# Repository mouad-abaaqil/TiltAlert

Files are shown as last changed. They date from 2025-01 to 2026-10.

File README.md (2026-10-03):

<p align="center">
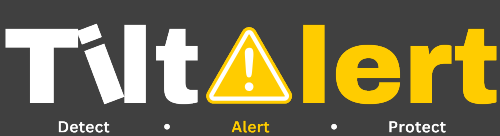
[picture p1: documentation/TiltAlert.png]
TiltAlert — Detect, Alert, Protect
  
</p>

<h1 align="center">Chaque choc laisse une trace.<br>Chaque colis mérite une preuve.</h1>

<p align="center">
  <strong>TiltAlert</strong> est la balise open source qui donne une mémoire aux colis fragiles.<br>
  Elle détecte chaque choc et chaque basculement, alerte sur place, et rend le trajet <em>lisible</em> : quand, à quelle force, avec quelle certitude de position.
</p>

<p align="center">
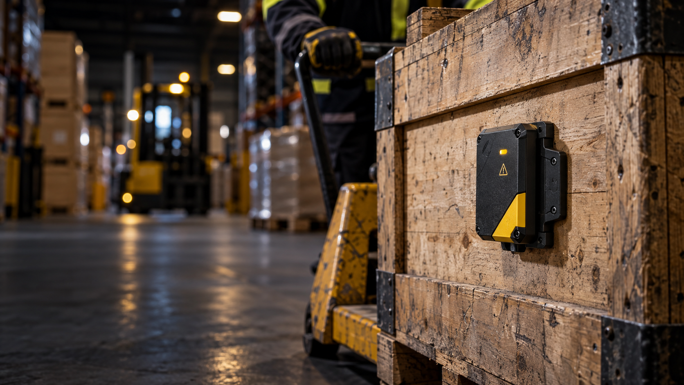
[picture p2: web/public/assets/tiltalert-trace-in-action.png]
Balise TiltAlert fixée à une caisse de transport en bois — visualisation du concept
  
</p>
<p align="center"><sub>Visualisation du concept (image générée, voir <a href="./documentation/IMAGE_PROMPT.md">le prompt</a>) — pas une photo d'un boîtier fabriqué.</sub></p>

---

## 1. Le problème : personne ne sait *quand* ça a cassé

Une optique de précision part de Paris et arrive à Lyon **fendue**. L'expéditeur, le transporteur et le destinataire voient le résultat. Personne ne peut dire **quand** le choc a eu lieu, **à quelle étape**, ni s'il s'agit d'une chute isolée ou d'un trajet entier mal manipulé.

Les étiquettes « FRAGILE » avertissent. Elles ne racontent rien. Résultat :

- des litiges où chacun renvoie la responsabilité à l'autre, **sans preuve** ;
- des assurances qui paient à l'aveugle, ou refusent à l'aveugle ;
- des étapes du transport qui restent mauvaises parce que **personne ne sait lesquelles** ;
- des indicateurs jetables qui disent « choc détecté » sans dire quand ni où.

## 2. La solution : une balise qui raconte le trajet

TiltAlert se fixe à une caisse. Elle fait trois choses, et les fait bien — **Detect, Alert, Protect** :

| | |
| --- | --- |
| **Detect — détecter** | Un accéléromètre dédié aux impacts (jusqu'à ±200 g) et un capteur d'inclinaison surveillent le colis en permanence, avec une consommation de veille de l'ordre du microampère. |
| **Alert — alerter** | LED, buzzer et bouton d'acquittement : après cinq basculements confirmés, l'alarme se déclenche **sur place**, là où quelqu'un peut encore réagir. |
| **Protect — prouver** | Chaque événement est enregistré dans un journal local (heure relative, valeur mesurée, état de la position). Le tableau de bord le transforme en **preuve intelligible** : carte, chronologie, rapport exportable. |

> **Pitch en 45 secondes.** « Vous expédiez une pièce fragile. Elle arrive cassée. Vous savez *quoi*, mais personne ne peut dire *quand* ni *à quelle étape*. TiltAlert donne une mémoire au colis : une balise réutilisable détecte l'incident, le journal le conserve et l'interface le rend compréhensible. Les équipes peuvent isoler les trajets problématiques au lieu de débattre sans preuve. Nous construisons un outil ouvert, réparable et adapté aux flux logistiques réels. »

### La règle d'or : on ne ment jamais sur la position

C'est le détail qui change tout. Un GNSS ne fonctionne pas dans un conteneur. Plutôt que de coller un point faux sur la carte, TiltAlert **affiche son niveau de certitude** :

| Statut | Ce que ça veut dire | Sur la carte |
| --- | --- | --- |
| ● **Position mesurée** | Un fix valide existe au moment exact de l'événement. | Marqueur plein |
| ○ **Dernière position connue** | Fix plus ancien : son âge est affiché, jamais présenté comme le lieu du choc. | Marqueur pointillé |
| — **Indisponible** | Aucun fix exploitable. | L'événement reste dans la chronologie, sans point |

Une preuve n'a de valeur que si elle dit aussi ce qu'elle ne sait pas.

---

## 3. Voir TiltAlert en action

### Le tableau de bord : « La vérité du trajet »

Carte interactive, journal d'incidents filtrable, replay du trajet, import de journal JSON, export CSV pour un litige ou un audit. [Code dans `web/`](./web/) — le trajet affiché est un **scénario de démonstration**, signalé comme tel dans l'interface.

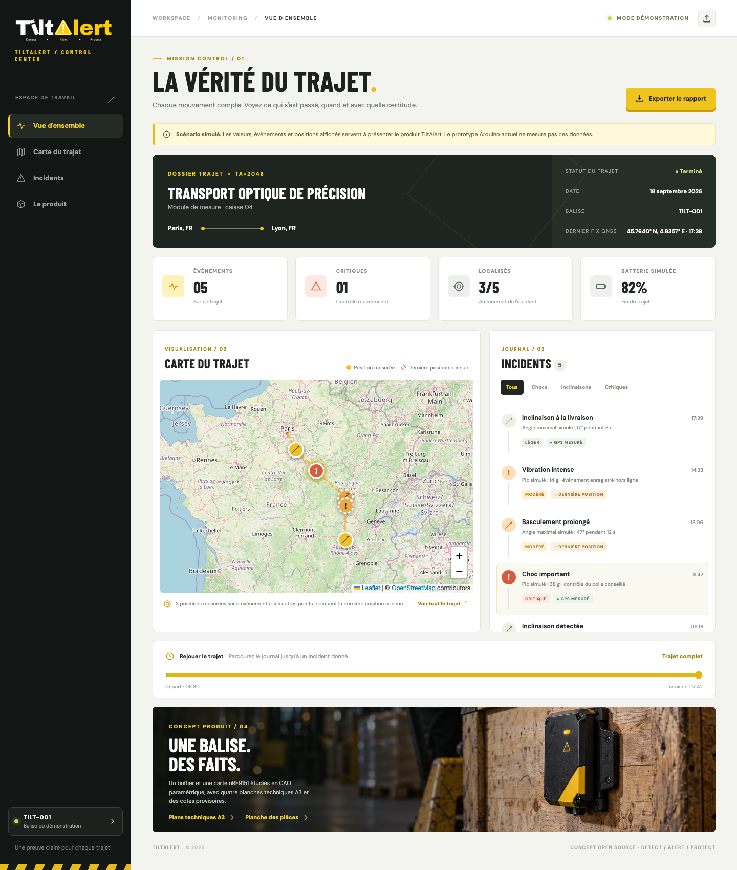
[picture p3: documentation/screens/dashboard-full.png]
Tableau de bord TiltAlert : dossier trajet, indicateurs, carte avec incidents mesurés et dernières positions connues, journal, replay


### Le blueprint : tous les composants sur une seule page

Vue éclatée de la balise V2 : **22 repères**, 25 lignes de nomenclature, axes de vissage, câble batterie. Tout est généré depuis un modèle 3D paramétrique, pas dessiné à la main.

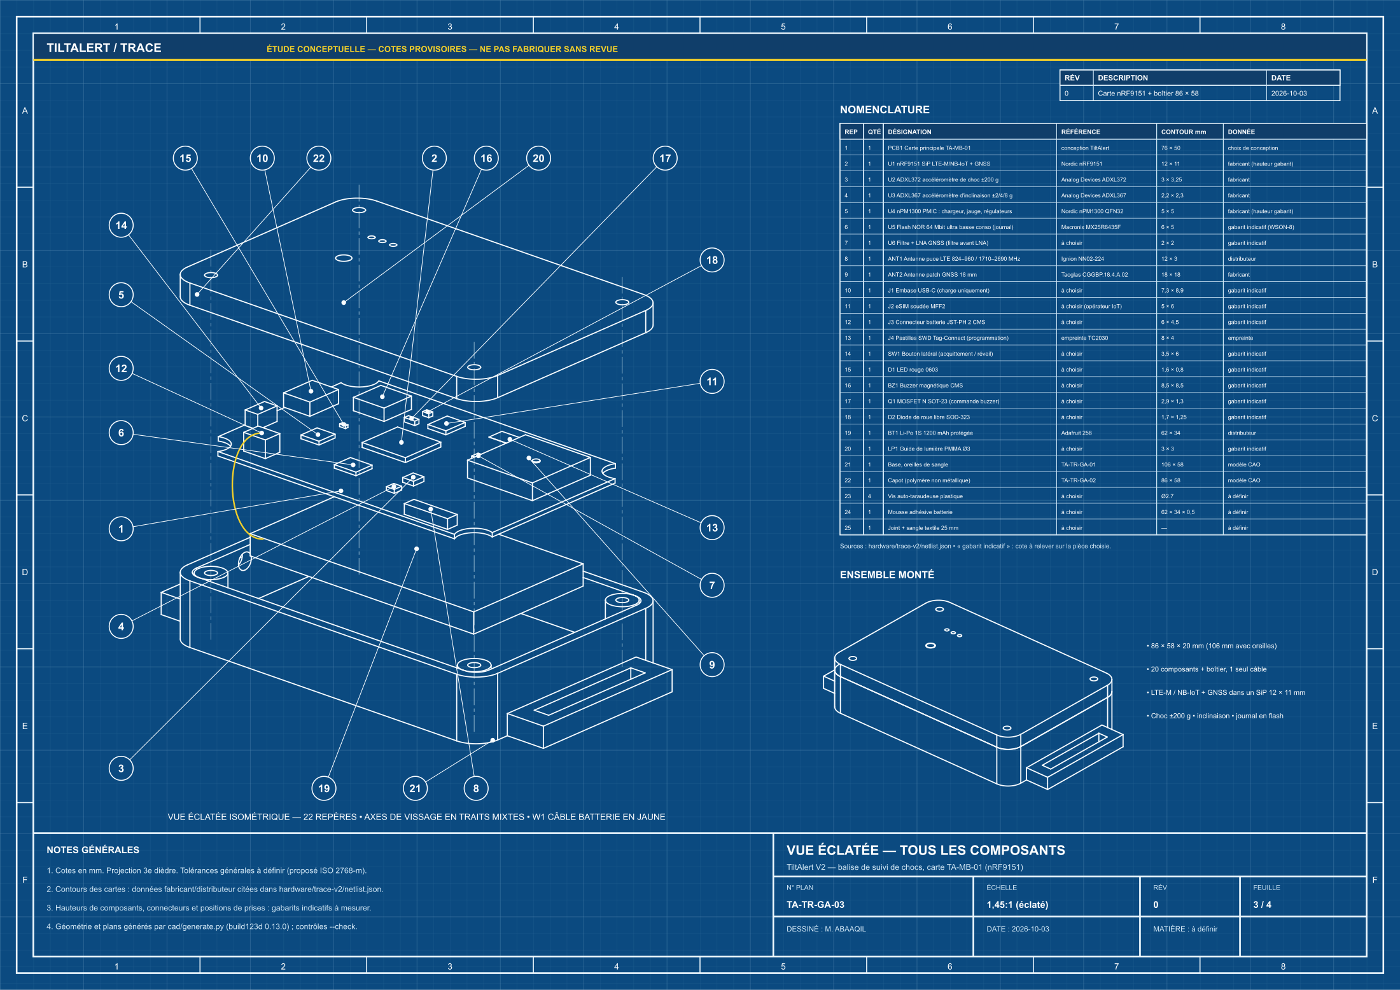
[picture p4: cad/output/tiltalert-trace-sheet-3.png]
Vue éclatée A3 de TiltAlert V2 : boîtier, carte nRF9151, capteurs, antennes, batterie, avec repères et nomenclature


<details>
<summary><strong>Voir les trois autres planches du jeu A3</strong> · <a href="./documentation/tiltalert-trace-plans-A3.pdf">PDF complet (4 pages)</a></summary>

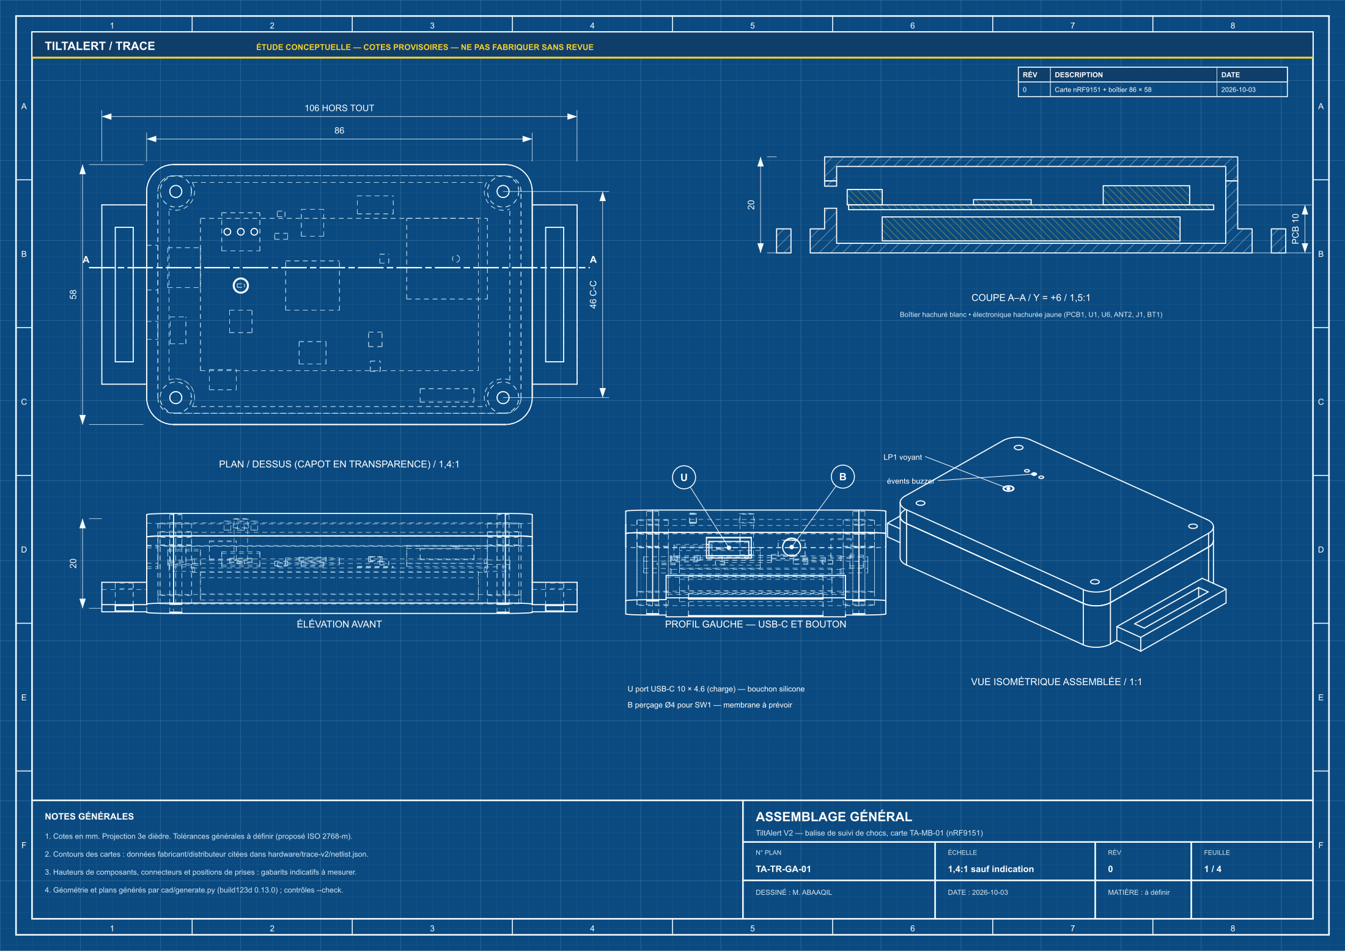
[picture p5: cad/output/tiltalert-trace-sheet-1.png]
Planche 1 : assemblage coté, coupe A–A, profil USB-C et bouton


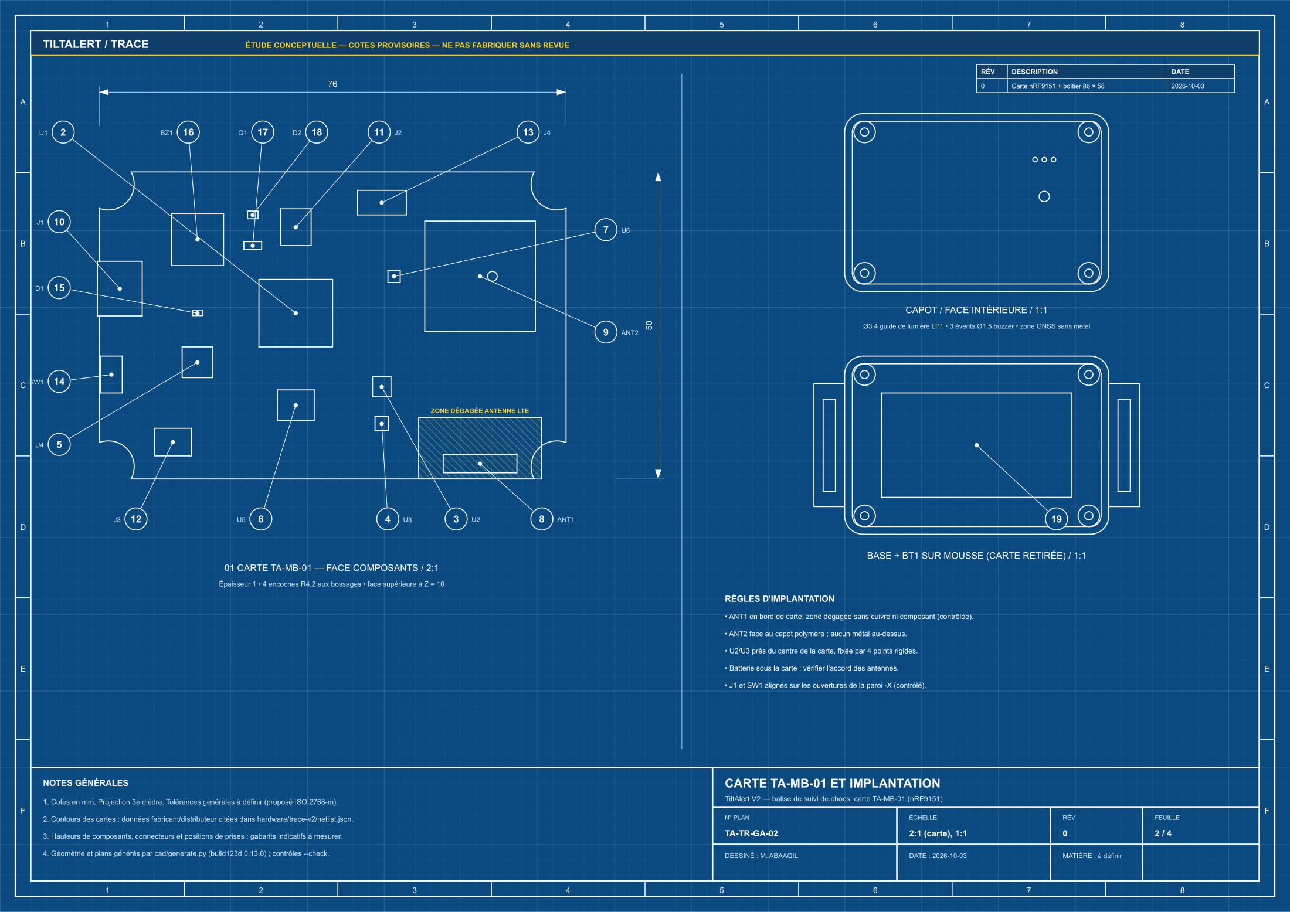
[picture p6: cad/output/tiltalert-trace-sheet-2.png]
Planche 2 : carte TA-MB-01 à 2:1, repères et zone dégagée de l'antenne LTE


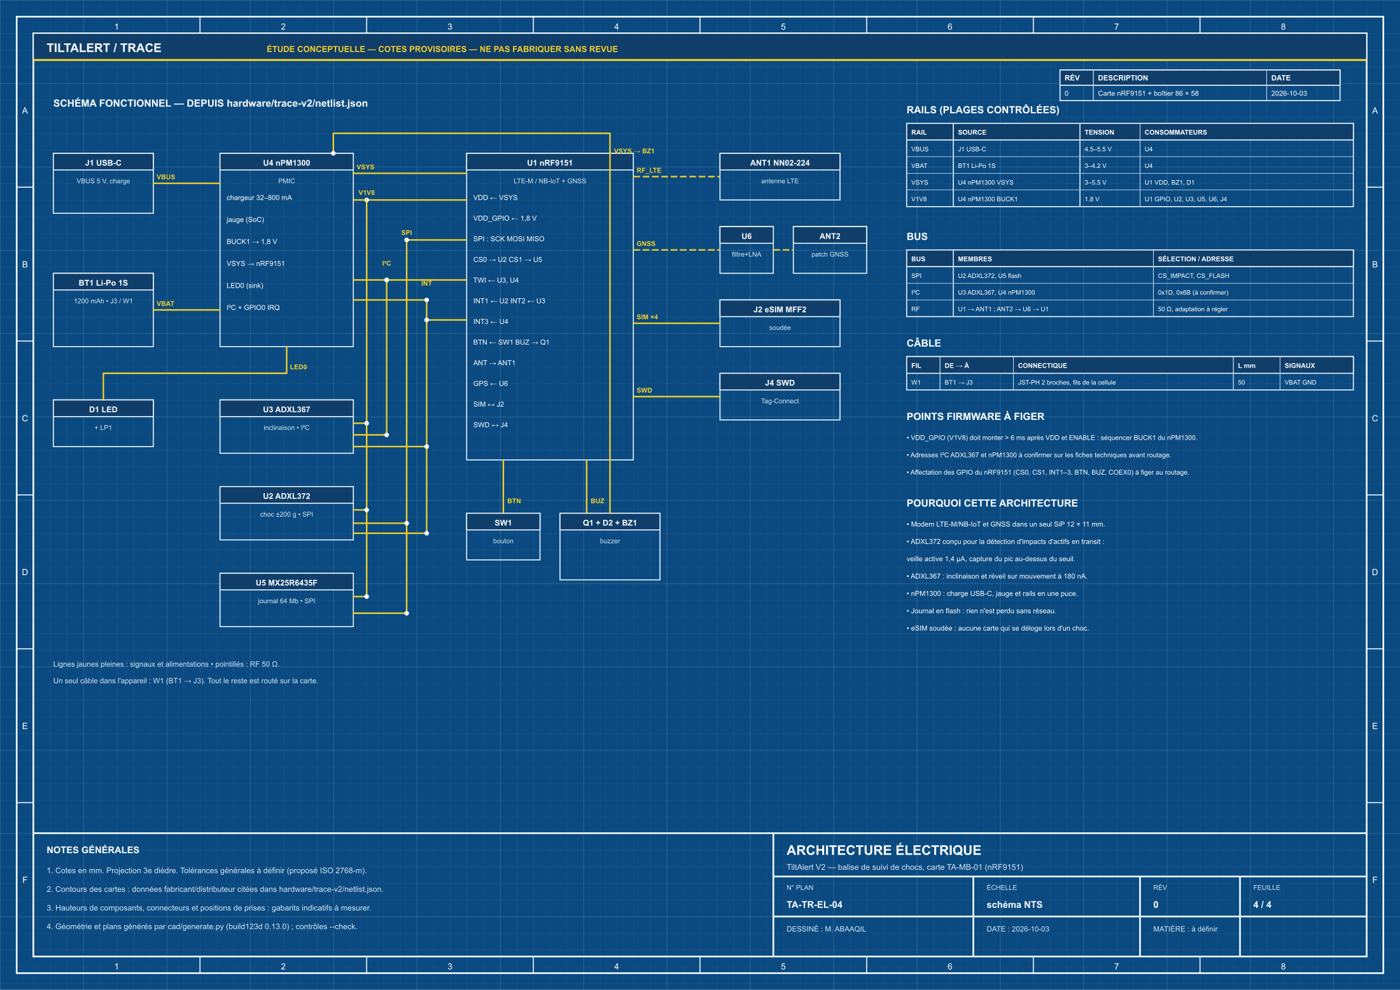
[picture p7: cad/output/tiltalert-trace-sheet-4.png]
Planche 4 : architecture électrique, rails, bus, câble


</details>

### Le blueprint de l'interface

Le tableau de bord lui-même est dessiné comme un plan : dix zones numérotées liées au vrai code, détail d'une carte d'incident, parcours utilisateur. [PDF](./documentation/tiltalert-interface-blueprint.pdf).

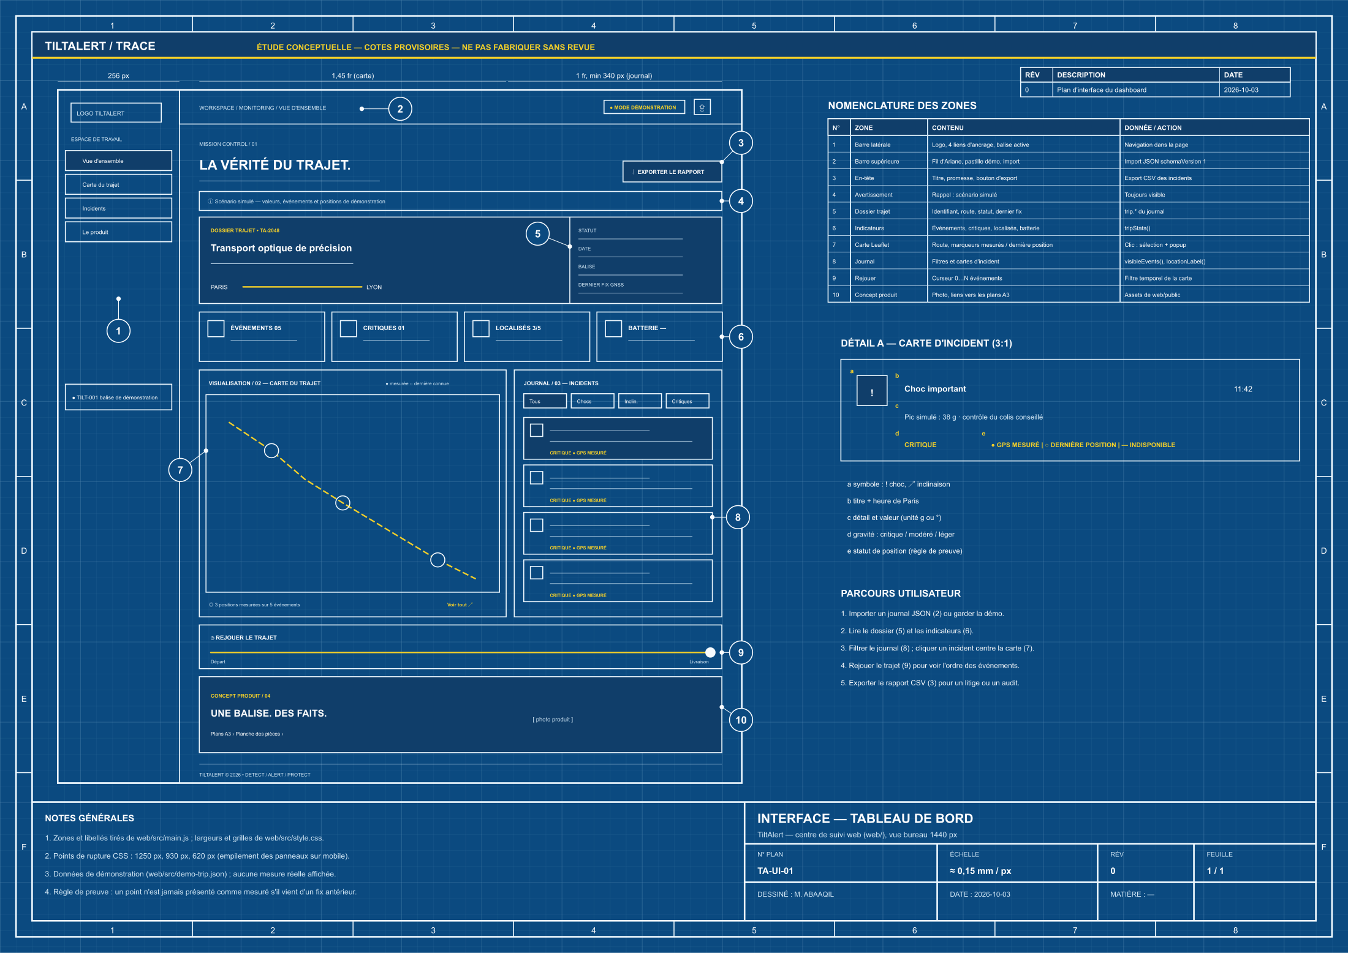
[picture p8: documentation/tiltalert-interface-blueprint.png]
Blueprint A3 de l'interface TiltAlert


### La preuve de concept : le vrai firmware, en simulation

Le firmware réel (`code/tiltalert.ino`) tourne dans un simulateur de l'Arduino Uno. Cinq basculements déclenchent l'alarme, un appui sur RESET l'acquitte.

| 1 · Cinq basculements → alarme | 2 · Acquittement |
| --- | --- |
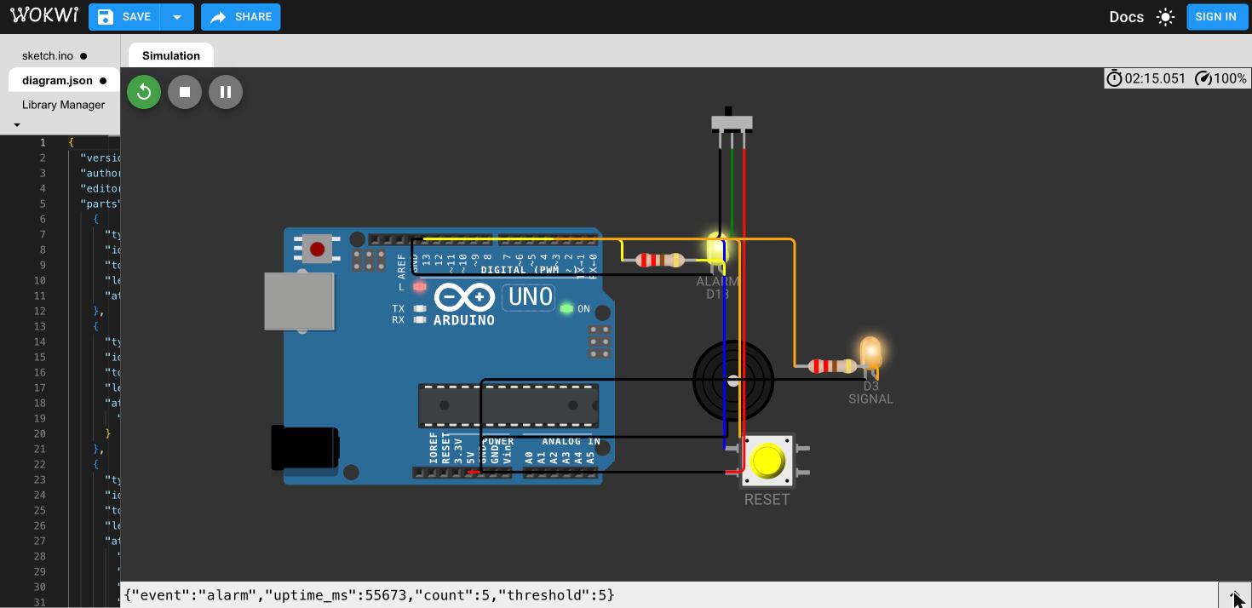
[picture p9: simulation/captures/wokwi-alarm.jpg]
Wokwi : alarme active, LED D13 et D3 allumées
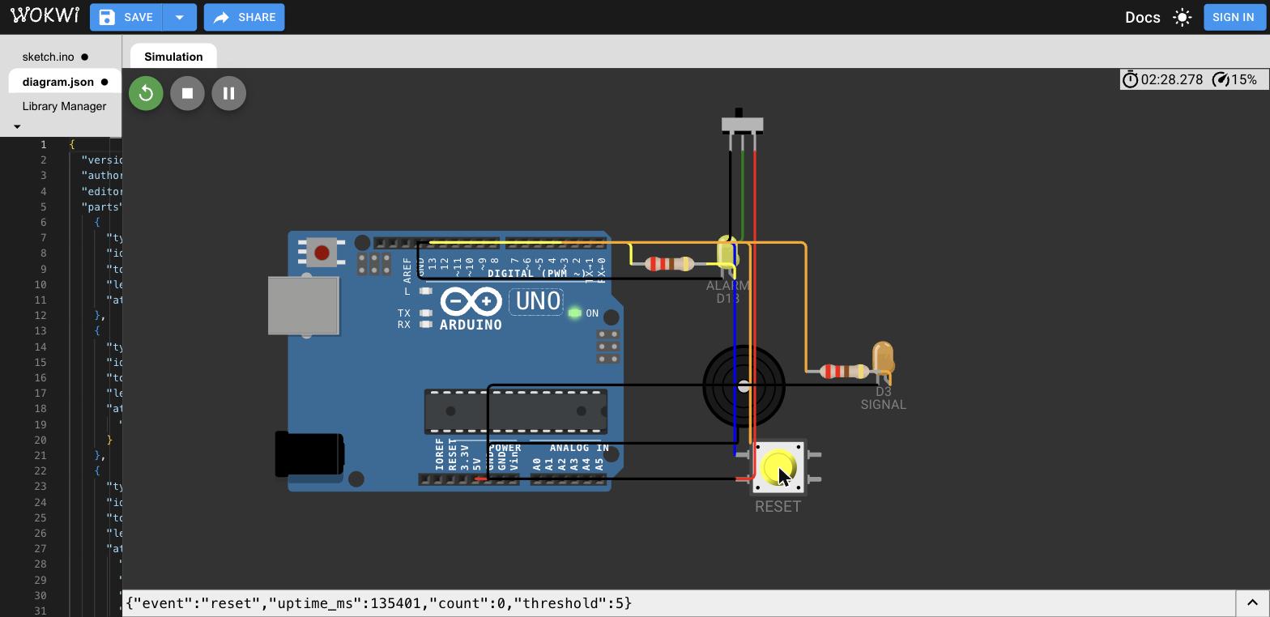
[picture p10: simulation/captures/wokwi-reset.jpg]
Wokwi : après RESET, LED éteintes
|  |  |

Le journal série prouve la séquence complète : `ready` → 5 × `tilt` → `alarm` → `reset`. [Capture du journal](./simulation/captures/wokwi-serial-log.jpg).

Le même prototype, documenté comme un vrai montage :

Schéma électrique A3 du prototype Uno

Implantation physique A3 sur breadboard, contrôlée contre la netlist

---

## 4. Sous le capot : la balise V2

Une **carte unique sur mesure** (TA-MB-01, 76 × 50 mm) dans un boîtier de **86 × 58 × 20 mm**. Chaque choix est sourcé dans [`hardware/trace-v2/`](./hardware/trace-v2/README.md).

| Fonction | Composant | Pourquoi celui-là |
| --- | --- | --- |
| Cerveau + réseau + GPS | [Nordic nRF9151](https://www.nordicsemi.com/Products/nRF9151) (12 × 11 mm) | Modem LTE-M/NB-IoT **et** GNSS intégrés : plus de modules empilés. |
| Chocs | [ADXL372](https://www.analog.com/en/products/adxl372.html), ±200 g | Conçu pour les impacts d'actifs en transit : veille active 1,4 µA, capture du pic au-dessus du seuil. |
| Inclinaison | [ADXL367](https://www.analog.com/en/products/adxl367.html) | Réveil sur mouvement à 180 nA. |
| Énergie | [nPM1300](https://www.nordicsemi.com/Products/nPM1300) | Charge USB-C, jauge de batterie et rails en une puce. |
| Mémoire | Flash 64 Mbit basse conso | Le journal survit sans réseau. |
| Antennes | Puce LTE + patch GNSS | Zone dégagée dédiée, contrôlée dans le modèle. |
| SIM | eSIM soudée | Aucune carte qui se déloge lors d'un choc. |

**Un seul câble** dans tout l'appareil (la batterie). Le reste est routé sur la carte.

### Un design qui se vérifie lui-même

À chaque génération des plans, un script contrôle que :

- les **20 composants tiennent** dans la cavité sans toucher une paroi, un bossage ou un autre composant (jeu ≥ 0,2 mm) ;
- chaque **tension d'alimentation** est dans la plage de chaque composant alimenté ;
- les **adresses I²C et sélections SPI** sont distinctes ;
- l'**antenne LTE** garde sa zone dégagée ;
- les ouvertures **USB-C et bouton** traversent bien la paroi en face de leurs composants.

Ces contrôles ont été éprouvés en leur injectant volontairement des erreurs (rail à 3,3 V, conflit d'adresse, composant dans la zone d'antenne) : ils les détectent.

```mermaid
flowchart LR
  A[ADXL372 : chocs ±200 g] --> M[nRF9151]
  B[ADXL367 : inclinaison] --> M
  G[GNSS intégré] --> M
  M --> J[(Journal flash)]
  J --> S[Export local ou LTE-M / NB-IoT]
  S --> W[Tableau de bord : carte + chronologie]
  M --> L[LED / buzzer / bouton]
  P[nPM1300 + Li-Po] --> M
```

---

## 5. Où en est-on, honnêtement

TiltAlert est un projet **ouvert et vérifiable**. Voici ce qui est prouvé, et ce qui reste à prouver avant toute promesse commerciale.

| ✅ Prouvé dans ce dépôt | 🔬 À prouver sur matériel réel |
| --- | --- |
| Firmware Uno : anti-rebond, seuil de 5 basculements, alarme latchée, acquittement, débordement de `millis()` — tests C++ et simulation du binaire compilé. | Calibration des seuils de choc et d'inclinaison sur un colis réel, taux de faux positifs. |
| Tableau de bord : format de trajet, statistiques, distinction des positions, export CSV — tests et build. | Journal qui survit à une coupure d'alimentation, sans doublons à la synchronisation. |
| Architecture V2 : netlist, rails, bus, encombrement et dégagements contrôlés par script. | Qualité des fixes GNSS en véhicule et en conteneur, accord des antennes. |
| Plans A3 générés depuis le modèle 3D, STEP/STL du boîtier et de l'assemblage. | Autonomie mesurée, tenue du boîtier, essais de transport. |

Les données du tableau de bord (événements, positions) sont **fictives**. Prix, autonomie, retour sur investissement : **non mesurés**. Les indicateurs d'impact et traceurs du marché existent déjà ([SpotSee](https://spotsee.io/wp-content/uploads/2019/07/Impact-Indicators-for-Packaging_English-01-19-2022-1.pdf), [Tive](https://www.tive.com/disposable-trackers/solo-pro-tracker)) : l'ambition de TiltAlert est une approche **ouverte, réparable et lisible**, avec une preuve qui dit ce qu'elle ne sait pas.

**Marché visé :** transport de pièces industrielles, matériel audiovisuel, objets fragiles de valeur. **Modèle à tester :** vente ou location de balises, puis abonnement pour la synchronisation et les rapports d'équipe.

### La suite

1. Écrire le firmware V2 sur une carte de développement [Nordic Thingy:91 X](https://docs.nordicsemi.com/r/bundle/ug_thingy91x/page/ug/thingy91x/intro/frontpage.html) : détection d'impacts, journal, envoi LTE-M, fix GNSS.
2. Router le PCB à 4 couches, revue RF.
3. Monter, mesurer, calibrer sur des chocs étalonnés.
4. Exporter de vrais journaux au format du tableau de bord.
5. Prototyper le boîtier et passer des essais de transport.

---

## 6. Explorer le dépôt

| Livrable | Contenu |
| --- | --- |
| [Tableau de bord](./web/) | Carte, chronologie, filtres, replay, import JSON, export CSV. |
| [Plans techniques A3](./documentation/tiltalert-trace-plans-A3.pdf) | 4 planches : assemblage, carte, vue éclatée + nomenclature, architecture électrique. |
| [Blueprint de l'interface](./documentation/tiltalert-interface-blueprint.pdf) | Zones numérotées, nomenclature, parcours utilisateur. |
| [Carte V2 nRF9151](./hardware/trace-v2/README.md) | Choix des composants, contrôles, points à lever avant routage. |
| [Modèle CAO](./cad/README.md) | build123d paramétrique ; exports STEP/STL (base, capot, assemblage complet). |
| [Architecture V2](./documentation/TRACE_ARCHITECTURE.md) | Flux d'un incident, règle de localisation, contrat de données. |
| [Prototype Uno](./hardware/validated-uno/README.md) | Netlist, schéma corrigé, implantation breadboard, nomenclature. |
| [Firmware](./code/tiltalert.ino) · [cœur testable](./code/TiltAlertCore.h) | Machine à états sans dépendance Arduino, sortie série JSON Lines. |
| [Simulation](./simulation/README.md) | AVR (binaire réel), circuit Wokwi, [captures](./simulation/captures/), [guide Tinkercad](./simulation/tinkercad/README.md). |
| [Cahier des charges original](./documentation/REPORT.md) | Archive de la première version. |

## 7. Reproduire

```bash
# Tests du firmware (C++) et du tableau de bord
sh tests/run.sh
cd web && npm ci && npm test && npm run build && cd ..

# Plans mécaniques et architecture V2 (Python 3.12, rsvg-convert)
python3.12 -m venv .venv
.venv/bin/python -m pip install -r cad/requirements.txt
.venv/bin/python cad/generate.py --check      # contrôles seuls
.venv/bin/python cad/generate.py              # plans, STEP, STL

# Planches du prototype Uno et blueprint de l'interface
python3 hardware/validated-uno/generate.py
python3 documentation/interface/generate.py

# Simulation du vrai firmware (arduino-cli + avr-gcc requis, voir simulation/README.md)
cd simulation && npm ci && npm test
```

**Lancer le tableau de bord :** `cd web && npm ci && npm run dev`, puis ouvrir l'adresse indiquée par Vite. Prérequis : Node.js 20.19+ ou 22.12+. La carte utilise [Leaflet](https://leafletjs.com/) et [OpenStreetMap](https://www.openstreetmap.org/copyright) (connexion Internet pour le fond de carte, aucune clé API).

**Monter le prototype Uno :** [schéma](./hardware/validated-uno/tiltalert-uno-electrical.pdf) et [implantation](./hardware/validated-uno/tiltalert-uno-physical.svg). Broches : D2 contact d'inclinaison (avec rappel 10 kΩ vers GND si le contact est nu), D3 buzzer **actif**, D13 LED + 220 Ω, D12 bouton vers GND (`INPUT_PULLUP`). Le fichier historique `hardware/wiring_diagram.brd` relie par erreur +5 V et GND : **ne pas le suivre**.

---

<p align="center">
  <strong>TiltAlert</strong> · Detect · Alert · Protect<br>
  <sub>Projet sous <a href="./LICENSE">licence MIT</a>. Cotes et architecture de conception, non validées pour la fabrication.</sub>
</p>

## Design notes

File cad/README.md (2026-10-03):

# TiltAlert — étude mécanique paramétrique

Ce dossier contient le **concept de boîtier et d'implantation de la V2** (carte TA-MB-01, nRF9151), distinct du montage Arduino Uno actuel. Les dimensions sont **provisoires**. Le PCB n'est pas routé ; l'étanchéité, la visserie et les tolérances d'assemblage ne sont pas validées. `components.py` modélise les composants et `drafting.py` le cadre A3 commun.

## Reproduire les exports

Sur macOS avec Python 3.12 et `rsvg-convert` :

```sh
python3.12 -m venv .venv
.venv/bin/python -m pip install -r cad/requirements.txt
.venv/bin/python cad/generate.py --check
.venv/bin/python cad/generate.py
```

Le modèle, la carte peuplée TA-MB-01 (contours sourcés dans `hardware/trace-v2/netlist.json`) et les quatre plans A3 sont générés depuis les paramètres `Dimensions` de [`generate.py`](generate.py). Les cotes, les positions des bossages, la coupe A–A, les vues orthographiques et la vue éclatée sont calculées depuis la même géométrie. `rsvg-convert` transforme les SVG en PDF et PNG. Tous les fichiers produits sont dans [`output/`](output/).

| Fichier | Usage |
|---|---|
| `tiltalert-trace-sheet-1.svg/.pdf/.png` | Assemblage : dessus, face, profil USB-C/bouton, coupe A–A, isométrie. |
| `tiltalert-trace-sheet-2.svg/.pdf/.png` | Carte TA-MB-01 à 2:1 avec repères et zone dégagée LTE, capot intérieur, batterie. |
| `tiltalert-trace-sheet-3.svg/.pdf/.png` | Vue éclatée repérée et nomenclature complète. |
| `tiltalert-trace-sheet-4.svg/.pdf/.png` | Architecture électrique : schéma fonctionnel, rails, bus, câble. |
| `tiltalert-trace-assembly.step` | Assemblage complet : boîtier, carte, composants, batterie. |
| `tiltalert-trace-base.step/.stl` | Solide de la base conceptuelle. |
| `tiltalert-trace-lid.step/.stl` | Solide du capot conceptuel. |

Le code de génération vérifie les dimensions extérieures, les volumes positifs, le perçage des quatre bossages, les ouvertures USB-C et bouton, la netlist V2 (rails, bus, câble) et l'absence de contact entre composants, parois et bossages (jeu ≥ 0,2 mm), y compris la zone dégagée de l'antenne LTE. Le script copie ensuite les feuilles vers `documentation/` et `web/public/assets/`. Ce contrôle géométrique ne remplace pas un essai d'impression, une revue mécanique, ni une validation de fabrication.

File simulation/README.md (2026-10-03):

# Simulation du firmware Uno

`npm test` compile **le vrai `code/tiltalert.ino`** avec le cœur Arduino AVR puis exécute le fichier Intel HEX dans [avr8js](https://github.com/wokwi/avr8js). Le script pilote les broches du microcontrôleur virtuel, écoute l'UART et vérifie D13 (LED) et D3 (buzzer). Le résultat reproductible est `evidence/avr8js-run.json`.

Pré-requis : Node 20.19+, `arduino-cli`, cœur `arduino:avr`, et un compilateur AVR utilisable par votre machine. Sur macOS ARM sans Rosetta, le compilateur AVR officiel Arduino est x86_64 : installer le compilateur natif avec `brew tap osx-cross/avr && brew trust osx-cross/avr && brew install avr-gcc`, puis `brew install universal-ctags`. Le script détecte ces outils dans le `PATH`; `AVR_COMPILER_PATH=/opt/homebrew/bin/ npm test` permet de fixer explicitement le compilateur.

```sh
arduino-cli core update-index
arduino-cli core install arduino:avr
cd simulation
npm ci
npm test
```

Le script de compilation copie le corps du sketch tel quel dans une unité C++ avec `#include <Arduino.h>` ; cela contourne la génération automatique de prototypes d'Arduino CLI, incompatible ici avec la variante de ctags ARM. Le scénario vérifie le démarrage, rejette un rebond de 10 ms, produit cinq transitions LOW→HIGH confirmées sur D2, confirme l'alarme sur D13 et D3, puis appuie sur le bouton D12 pour la réinitialiser. La simulation vérifie la logique et la correspondance des broches du firmware ; elle ne mesure ni les courants, ni l'acoustique du KY-012, ni le comportement physique du KY-020.

`wokwi/diagram.json` offre une version visuelle du même câblage. Le switch D2 sélectionne 0 V ou 5 V pour reproduire l'état logique OUT du KY-020 ; maintenir chaque position plus de 40 ms. Le bouton D12 correspond au reset. La LED orange supplémentaire témoigne de la sortie D3, car le buzzer piézo passif proposé par Wokwi ne représente pas exactement le module **actif** KY-012 alimenté en continu. `wokwi/sketch.ino` est généré depuis le firmware avec `npm run wokwi:generate` ; il ne doit pas être modifié à la main. Le même fichier sert au montage [Tinkercad](./tinkercad/README.md).

Le 3 octobre 2026, un essai interactif dans Wokwi (`diagram.json` + `sketch.ino` chargés tels quels) a affiché successivement `ready`, cinq événements `tilt` puis `alarm` à `count=5`, avec les LED D13 et D3 allumées, puis `reset` à `count=0` après appui sur RESET, LED éteintes. Les [captures](./captures/) le montrent : [démarrage](./captures/wokwi-ready.jpg), [alarme](./captures/wokwi-alarm.jpg), [acquittement](./captures/wokwi-reset.jpg) et [journal série complet](./captures/wokwi-serial-log.jpg). Le reset est aussi couvert par le test AVR automatique. Remarque de reproduction : l'onglet doit être visible, sinon le navigateur ralentit la simulation à quelques pour cent et les basculements sont trop brefs pour passer l'anti-rebond de 40 ms. Le [chronogramme SVG](./evidence/avr8js-timeline.svg) est généré depuis la trace réelle par `python3 generate-evidence.py` ; il montre les cinq événements, l'alarme et le reset, sans inventer de mesure analogique.

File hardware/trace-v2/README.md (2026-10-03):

# TiltAlert V2 — carte TA-MB-01 (nRF9151)

**Statut : architecture de conception sourcée.** Le PCB n'est ni routé, ni fabriqué, ni testé. Ce dossier ne décrit pas le prototype Uno de `code/` : celui-ci reste la preuve de concept logique.

La V2 remplace la pile de modules MKR envisagée au départ par **une seule carte sur mesure**. Le modem cellulaire et le GNSS sont intégrés dans un même boîtier SiP, et des capteurs conçus pour le suivi de colis sur batterie complètent la carte. Le boîtier passe ainsi d'environ 124 × 84 × 36 mm (encombrement de la pile MKR) à **86 × 58 × 20 mm**.

## Plans

| Planche | Contenu |
|---|---|
| [Feuille 1 — assemblage](../../cad/output/tiltalert-trace-sheet-1.pdf) | Vues cotées, coupe A–A à travers U1/ANT2/J1, profil USB-C + bouton, isométrie. |
| [Feuille 2 — carte et implantation](../../cad/output/tiltalert-trace-sheet-2.pdf) | Face composants 2:1 avec repères, zone dégagée de l'antenne LTE, capot intérieur, batterie. |
| [Feuille 3 — éclaté et nomenclature](../../cad/output/tiltalert-trace-sheet-3.pdf) | Vue éclatée repérée, 25 lignes de nomenclature avec statut de chaque cote. |
| [Feuille 4 — architecture électrique](../../cad/output/tiltalert-trace-sheet-4.pdf) | Schéma fonctionnel, rails contrôlés, bus, câble unique, points firmware. |

Le jeu complet est aussi disponible dans [`tiltalert-trace-plans-A3.pdf`](../../documentation/tiltalert-trace-plans-A3.pdf). Les quatre feuilles sont générées par `cad/generate.py` à partir de [`netlist.json`](./netlist.json) et du modèle 3D.

## Choix des composants

| Rep. | Composant | Pourquoi |
|---|---|---|
| U1 | [Nordic nRF9151](https://www.nordicsemi.com/Products/nRF9151) SiP 12 × 11 mm | Modem LTE-M/NB-IoT **et** GNSS intégrés, processeur Cortex-M33 applicatif. Remplace le MKR NB 1500 et le module GNSS séparé. |
| U2 | [ADXL372](https://www.analog.com/en/products/adxl372.html) ±200 g | Conçu pour la surveillance d'impacts sur des biens en transit : veille active de 1,4 µA, capture du seul pic au-dessus du seuil, FIFO profond. |
| U3 | [ADXL367](https://www.analog.com/en/products/adxl367.html) ±2/4/8 g | Inclinaison par la gravité et réveil sur mouvement à 180 nA. |
| U4 | [nPM1300](https://www.nordicsemi.com/Products/nPM1300) | Chargeur 32–800 mA, jauge, deux régulateurs abaisseurs et pilotes de LED dans une seule puce. |
| U5 | Macronix MX25R6435F, 64 Mbit | Journal non volatil : rien n'est perdu sans réseau. Courant de 7 nA en mise en veille profonde. |
| U6 + ANT2 | Filtre puis LNA + patch [Taoglas CGGBP.18.4.A.02](https://www.taoglas.com/product/cggbp-18-4-a-02-gpsglonassbeidou-patch-antenna-18mm-2) | Topologie [recommandée par Nordic](https://docs.nordicsemi.com/r/bundle/nwp_056/page/wp/nwp_054/gps_if.html) avec une antenne passive. |
| ANT1 | Ignion NN02-224 (12 × 3 × 2,4 mm) | Antenne puce LTE couvrant 824–960 et 1710–2690 MHz, placée en bord de carte. |
| J2 | eSIM soudée MFF2 | Aucune carte SIM ne peut se déloger lors d'un choc. |
| BT1 | Li-Po 1S 1200 mAh protégée ([Adafruit 258](https://www.adafruit.com/product/258), 62 × 34 × 5 mm) | Cellule protégée et prise JST-PH, posée sur de la mousse sous la carte. |

Le nRF9151 n'a **pas d'USB natif**. Le port USB-C sert uniquement à la charge (VBUS vers le nPM1300). La programmation passe par des pastilles SWD Tag-Connect (J4).

Pour développer le firmware avant de fabriquer le PCB, la [Nordic Thingy:91 X](https://docs.nordicsemi.com/r/bundle/ug_thingy91x/page/ug/thingy91x/intro/frontpage.html) réunit le nRF9151, un PMIC nPM1300 et une batterie de 1350 mAh.

## Ce que les scripts vérifient

`cad/generate.py --check` contrôle, à chaque génération :

- **Netlist :**
  - chaque broche d'alimentation se trouve sur le rail déclaré ;
  - la plage de chaque rail tient dans la plage du composant (par exemple V1V8 dans 1,6–3,5 V pour l'ADXL372, VSYS dans 3,0–5,5 V pour le VDD du nRF9151) ;
  - aucune broche n'est reliée à deux réseaux, et chaque circuit intégré a une masse ;
  - les sélections SPI sont distinctes, les adresses I²C aussi, et chaque membre est bien sur son bus.
- **Mécanique :**
  - les 20 pièces sont dans la cavité ;
  - aucune ne touche une autre pièce, une paroi ou un bossage (jeu minimal de 0,2 mm) ;
  - les composants sont posés sur la carte, et aucun n'entre dans la zone dégagée de l'antenne LTE ;
  - les ouvertures USB-C et bouton traversent bien la paroi en face de J1 et SW1.

Ces contrôles ne remplacent ni un routage, ni une simulation RF, ni des essais.

## Points à lever avant le routage

1. **Séquencement :** VDD_GPIO (1,8 V) doit monter plus de 6 ms après VDD et ENABLE. Il faut le programmer sur le BUCK1 du nPM1300.
2. **Adresses I²C :** celles de l'ADXL367 (0x1D prévue) et du nPM1300 (0x6B prévue) sont à confirmer sur les fiches techniques.
3. **GPIO du nRF9151 :** leur affectation (CS0, CS1, INT1–3, BTN, BUZ, COEX0) est à figer au routage.
4. **Antennes :**
   - accord des antennes avec la batterie sous la carte et le capot final ;
   - zone dégagée LTE conforme à la fiche Ignion ;
   - patch GNSS sans aucun métal au-dessus.
5. **Fixation mécanique :** les accéléromètres doivent être couplés rigidement au boîtier, sinon la mesure du choc est faussée. Les 4 points de fixation de la carte restent à définir.
6. **Marge d'alimentation :** VSYS sur batterie descend jusqu'à 3,0 V (coupure de protection), soit exactement le minimum du VDD du nRF9151. Il ne reste donc aucune marge pour les chutes lors des émissions LTE. Il faut mesurer la tension minimale sous émission et, si besoin, arrêter l'appareil plus tôt par la jauge (seuil logiciel).
7. **Budget d'énergie :** il est à mesurer (par exemple au Power Profiler Kit) sur des profils de transport réels. Aucune autonomie n'est annoncée.

## Ordre de validation

1. Écrire le firmware sur Thingy:91 X : détection d'impacts, journal, envoi LTE-M, fix GNSS.
2. Router le PCB à 4 couches, puis faire une revue RF et une revue d'implantation.
3. Monter la carte : vérifier les rails, le séquencement, le SWD, puis la lecture des capteurs.
4. Faire des essais de chocs étalonnés, d'inclinaison et de faux positifs, carte fixée dans le boîtier.
5. Vérifier la qualité des fixes GNSS en extérieur et en véhicule, et l'enregistrement hors réseau.
6. Mesurer l'autonomie, la charge et la tenue en température avant toute promesse produit.

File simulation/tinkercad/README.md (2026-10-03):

# Variante Tinkercad Circuits (guide, non réalisée)

Les captures de la preuve de concept ont été faites dans Wokwi (voir [`../captures/`](../captures/)), car Tinkercad ne sait pas importer un circuit décrit en code : tout y est placé à la main. Ce guide reste valable pour refaire le montage dans Tinkercad.

Ce montage reproduit dans [Tinkercad Circuits](https://www.tinkercad.com/circuits) le circuit Uno validé ([`hardware/validated-uno/netlist.json`](../../hardware/validated-uno/netlist.json)) et exécute le firmware réel. Il complète la [simulation AVR automatique](../README.md), sans la remplacer. Ici, l'objectif est d'obtenir des **captures visuelles** pour la présentation.

## Code

L'éditeur de Tinkercad n'accepte qu'un seul fichier. Utiliser [`../wokwi/sketch.ino`](../wokwi/sketch.ino) : c'est le firmware `code/tiltalert.ino` avec `TiltAlertCore.h` intégré, généré par `npm run wokwi:generate`. Dans Tinkercad, ouvrir **Code → Texte**, tout remplacer par ce fichier, puis lancer la simulation.

## Câblage (identique à la netlist)

| Pièce Tinkercad | Raccordement | Réseau |
|---|---|---|
| Arduino Uno R3 | 5V → rail +, GND → rail − | `+5V`, `GND` |
| Interrupteur à glissière (à la place du KY-020) | broche commune → D2 ; une extrémité → rail + | `TILT_D2` |
| Résistance 10 kΩ (R1) | D2 → rail − | rappel de D2 |
| Bouton-poussoir (S2) | D12 → bouton → rail − | `RESET_D12` (INPUT_PULLUP) |
| Résistance 220 Ω (R2) + LED rouge (D1) | D13 → R2 → anode ; cathode → rail − | `ALARM_D13`, `LED_A` |
| Résistance 220 Ω + LED orange | D3 → résistance → anode ; cathode → rail − | `BUZZ_D3` (témoin) |

Deux substitutions, comme dans la version Wokwi :

- **Capteur :** l'interrupteur remplace la sortie logique du contact d'inclinaison. Il ne modélise ni la mécanique, ni un choc.
- **Buzzer :** le firmware applique un niveau HIGH continu sur D3, prévu pour un buzzer **actif**. Le piézo de Tinkercad est passif et resterait muet avec ce signal. Une LED témoin affiche donc l'état de D3.

## Scénario de capture

1. Démarrer la simulation, puis ouvrir le moniteur série : la ligne `{"event":"ready",...}` s'affiche.
2. Basculer l'interrupteur 5 fois (aller-retour, en maintenant chaque position plus de 40 ms) : 5 lignes `tilt` s'affichent.
3. Au 5ᵉ basculement, la ligne `alarm` apparaît et les LED D13 et D3 s'allument. **Capture 1 : alarme.**
4. Appuyer sur le bouton : la ligne `reset` apparaît et les LED s'éteignent. **Capture 2 : acquittement.**

Les captures sont à enregistrer dans ce dossier (`tinkercad-alarm.png`, `tinkercad-reset.png`), avec le lien public du projet Tinkercad s'il est partagé.

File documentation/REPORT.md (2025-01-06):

<p align="center">
  Logo TiltAlert
</p>

# Cahier des Charges - Projet TiltAlert

## 1. Introduction
TiltAlert est un projet basé sur Arduino qui permet de surveiller des colis ou équipements sensibles en détectant les chocs et les inclinaisons critiques. Ce dispositif offre une alerte sonore et visuelle en cas de mouvement anormal, et il est réinitialisable pour une utilisation multiple.

### Objectif
Fournir une solution abordable et efficace pour le transport sécurisé de biens fragiles ou sensibles aux chocs.

---

## 2. Analyse des Besoins

### 2.1 Fonctionnalités Requises
- Détection précise des inclinaisons critiques.
- Alerte sonore avec buzzer (KY-012).
- Alerte visuelle avec une LED rouge.
- Possibilité de réinitialisation via un bouton poussoir (KY-004).

### 2.2 Contraintes
- **Technique** : 
  - Doit être compatible avec un Arduino Uno.
  - Alimenté via USB ou batterie portable.
- **Pratique** : 
  - Facile à intégrer dans un boîtier compact.
  - Doit fonctionner dans des environnements variés (température ambiante normale).
- **Budget** : 
  - Conception avec des composants économiques et facilement accessibles.

### 2.3 Applications
- Transport logistique : Surveillance de colis fragiles.
- Industries : Surveillance des équipements sensibles.
- Usage personnel : Suivi des objets fragiles pendant un déplacement.

---

## 3. Spécifications Techniques

### 3.1 Matériel Utilisé
- 1x Arduino Uno
- 1x Capteur KY-020 (inclinaison)
- 1x Buzzer KY-012
- 1x Bouton poussoir KY-004
- 1x LED rouge
- Résistances : 220 Ω, 10 kΩ
- Breadboard
- Câbles de connexion

### 3.2 Fonctionnement
1. Lorsqu'une inclinaison critique est détectée par le capteur KY-020, le système incrémente un compteur interne.
2. Si le nombre d'inclinaisons détectées atteint le seuil (5), une LED rouge s'allume et le buzzer émet un son continu.
3. L'utilisateur peut réinitialiser le système via un bouton poussoir pour recommencer une nouvelle surveillance.

### 3.3 Schéma de Câblage
Le schéma de câblage complet est disponible dans le fichier `wiring_diagram.png`.

---

## 4. Tests et Validation

### 4.1 Scénarios de Test
- Inclinaison simulée avec le capteur KY-020 pour vérifier le seuil critique.
- Activation des alertes visuelles et sonores.
- Réinitialisation via le bouton poussoir.

### 4.2 Résultats Attendus
- Inclinaison détectée : LED et buzzer activés lorsque le seuil est atteint.
- Réinitialisation : Compteur remis à zéro, LED et buzzer éteints.

---

## 5. Améliorations Futures
- Ajout d'un module Bluetooth pour envoyer des notifications sur smartphone.
- Remplacement du capteur KY-020 par un accéléromètre pour une détection plus précise.
- Intégration dans un boîtier imprimé en 3D pour une solution plus robuste.

---

## 6. Conclusion
Le projet TiltAlert est une solution simple et abordable pour la surveillance des objets fragiles. Son architecture basée sur Arduino permet une personnalisation et une évolutivité importantes.

---

Pour toute question ou suggestion d'amélioration, n'hésitez pas à contribuer via le repository GitHub !

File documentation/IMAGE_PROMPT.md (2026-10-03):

# Visuel du produit en action

Image finale : [`web/public/assets/tiltalert-trace-in-action.png`](../web/public/assets/tiltalert-trace-in-action.png).

Ce visuel est une **projection photoréaliste** du concept, générée avec l'outil ImageGen intégré. Il ne montre pas un boîtier fabriqué ni testé. Les [plans techniques](./tiltalert-trace-plans-A3.pdf) proviennent séparément du modèle CAO codé dans [`cad/`](../cad/) ; les deux références de [`ref/`](../ref/) ont guidé le choix des vues et du cartouche.

## Prompt utilisé

> Photographie produit réaliste et horizontale, destinée au tableau de bord d'une balise open source de suivi logistique. Une petite balise réutilisable TiltAlert est fixée sur une caisse de transport en bois, dans un entrepôt moderne. Boîtier rectangulaire de la taille de la paume, noir mat, accent diagonal jaune de sécurité, petit voyant jaune, pictogramme triangulaire d'alerte, fixation robuste. Une main gantée déplace la caisse ; la balise est nette, l'arrière-plan de l'entrepôt et un chariot élévateur sont flous. Matériaux et proportions crédibles, éclairage naturel dramatique, palette noir mat, jaune chantier, bois patiné et gris anthracite. Balise située à droite du cadre, espace sombre à gauche pour du texte. Aucun mot lisible, aucune interface flottante et aucun filigrane.

La photo sert à communiquer la direction du produit. Les [plans mécaniques](./tiltalert-trace-plans-A3.pdf) documentent les dimensions provisoires ; la fabrication exige encore une validation des composants et du matériel réel.

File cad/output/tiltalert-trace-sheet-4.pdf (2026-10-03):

1

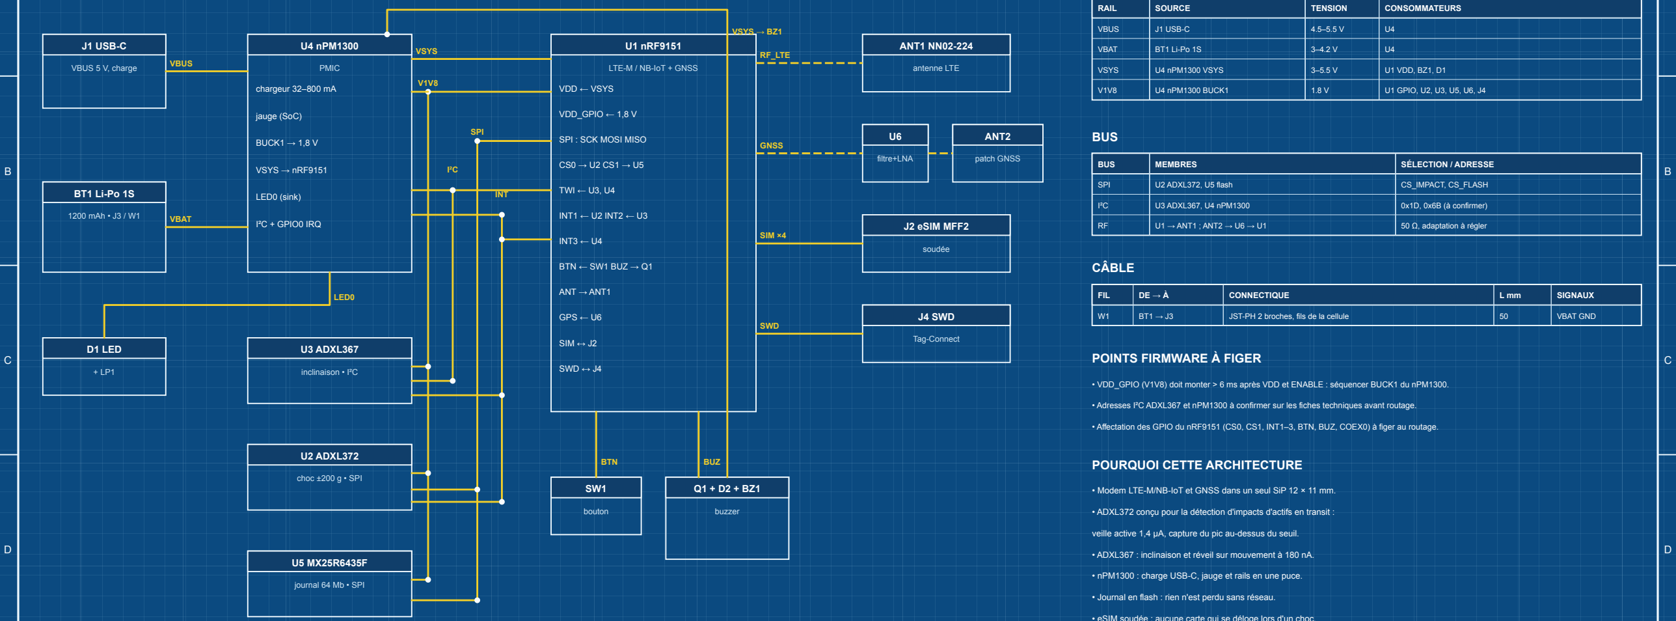
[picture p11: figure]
J1 USB-C; VBUS 5 V, charge; 1200 mAh • J3 / W1; U4 nPM1300; PMIC; chargeur 32–800 mA; jauge (SoC); BUCK1 → 1,8 V; VSYS → nRF9151; LED0 (sink); I²C + GPIO0 IRQ; U1 nRF9151; LTE-M / NB-IoT + GNSS; VDD ← VSYS; VDD_GPIO ← 1,8 V; SPI : SCK MOSI MISO; TWI ← U3, U4; INT1 ← U2 INT2 ← U3; INT3 ← U4; BTN ← SW1 BUZ → Q1; ANT → ANT1; GPS ← U6; SIM ↔ J2; SWD ↔ J4; ANT1 NN02-224; antenne LTE; filtre+LNA; ANT2; patch GNSS; J2 eSIM MFF2; soudée; J4 SWD; Tag-Connect; U3 ADXL367; inclinaison • I²C; U2 ADXL372; choc ±200 g • SPI; journal 64 Mb • SPI; bouton; buzzer; D1 LED; VBUS; VBAT; VSYS; VSYS → BZ1; LED0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
A | A
E | E
F | F
TILTALERT / TRACE | ÉTUDE CONCEPTUELLE — COTES PROVISOIRES — NE PAS FABRIQUER SANS REVUE
RÉV | DESCRIPTION | DATE
0 | Carte nRF9151 + boîtier 86 × 58 | 2026-10-03

## NOTES GÉNÉRALES

1. Cotes en mm. Projection 3e dièdre. Tolérances générales à définir (proposé ISO 2768-m).
2. Contours des cartes : données fabricant/distributeur citées dans hardware/trace-v2/netlist.json.
3. Hauteurs de composants, connecteurs et positions de prises : gabarits indicatifs à mesurer.
4. Géométrie et plans générés par cad/generate.py (build123d 0.13.0) ; contrôles --check.

# ARCHITECTURE ÉLECTRIQUE

TiltAlert V2 — balise de suivi de chocs, carte TA-MB-01 (nRF9151)

N° PLAN

## TA-TR-EL-04

ÉCHELLE

## schéma NTS

RÉV
0

FEUILLE
4 / 4
DESSINÉ : M. ABAAQIL | DATE : 2026-10-03 | MATIÈRE : à définir

## SCHÉMA FONCTIONNEL — DEPUIS hardware/trace-v2/netlist.json

Lignes jaunes pleines : signaux et alimentations • pointillés : RF 50 Ω.

Un seul câble dans l'appareil : W1 (BT1 → J3). Tout le reste est routé sur la carte.

## RAILS (PLAGES CONTRÔLÉES)

V1V8 | U4 nPM1300 BUCK1 | 1.8 V | U1 GPIO, U2, U3, U5, U6, J4
RF | U1 → ANT1 ; ANT2 → U6 → U1 | 50 Ω, adaptation à régler
W1 | BT1 → J3 | JST-PH 2 broches, fils de la cellule | 50 | VBAT GND
- VDD_GPIO (V1V8) doit monter > 6 ms après VDD et ENABLE : séquencer BUCK1 du nPM1300.
- Adresses I²C ADXL367 et nPM1300 à confirmer sur les fiches techniques avant routage.
- Affectation des GPIO du nRF9151 (CS0, CS1, INT1–3, BTN, BUZ, COEX0) à figer au routage.
- Modem LTE-M/NB-IoT et GNSS dans un seul SiP 12 × 11 mm.
- ADXL372 conçu pour la détection d'impacts d'actifs en transit :

veille active 1,4 µA, capture du pic au-dessus du seuil.

- ADXL367 : inclinaison et réveil sur mouvement à 180 nA.
- nPM1300 : charge USB-C, jauge et rails en une puce.
- Journal en flash : rien n'est perdu sans réseau.
- eSIM soudée : aucune carte qui se déloge lors d'un choc.

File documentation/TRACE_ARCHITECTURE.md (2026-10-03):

# TiltAlert — architecture de concept

Plan technique d'assemblage de TiltAlert

[Ouvrir les quatre plans techniques A3](./tiltalert-trace-plans-A3.pdf) · [Carte V2 nRF9151](../hardware/trace-v2/README.md) · [Source CAO et exports](../cad/README.md)

> **Statut : concept de produit, pas prototype matériel validé.** Les vues mécaniques sont issues d'un modèle paramétrique coté ; leurs dimensions restent provisoires. Elles ne constituent ni un dépôt de brevet, ni un dossier de fabrication validé, ni un schéma électrique.

## Promesse du produit

TiltAlert est une balise réutilisable pour colis et équipements fragiles. Elle conserve une chronologie des chocs et des changements d'orientation, puis aide à comprendre **quand** un incident s'est produit et **quelle position était connue** à ce moment. L'interface associe chaque événement à son niveau de preuve ; elle ne transforme pas une dernière position connue en position exacte du choc.

La version présente dans ce dépôt est un montage Arduino Uno avec capteur de basculement KY-020, LED, buzzer et bouton. Le code compte les transitions du capteur et déclenche l'alarme au cinquième basculement. Le KY-020 fournit un état binaire : il ne mesure ni intensité du choc, ni angle précis. Il n'y a actuellement ni stockage persistant, ni horodatage fiable, ni géolocalisation, ni connexion radio. TiltAlert décrit la prochaine génération envisagée, sans attribuer ces capacités au montage existant.

## Modules envisagés

| Module V2 | Rôle | Point à valider sur prototype |
| --- | --- | --- |
| Boîtier et fixation | Protéger l'électronique et permettre une pose/reprise répétée sur une caisse ou un colis. | Résistance mécanique, accès à la charge, maintien, matériaux, étanchéité éventuelle. |
| Capteur inertiel + microcontrôleur + mémoire non volatile | Mesurer accélération et orientation, classifier l'événement, horodater et garder le journal hors réseau. | Plage et fréquence de mesure adaptées au cas d'usage ; calibration, faux positifs, pertes d'écriture. |
| Récepteur GNSS + liaison radio optionnelle | Obtenir des positions quand les conditions le permettent et synchroniser le journal. | Sensibilité en situation réelle, coût énergétique, couverture et réglementation de la liaison choisie. |
| Batterie rechargeable et circuit de protection | Assurer l'autonomie et enregistrer son état. | Autonomie sur profils de transport réels, sécurité de charge et température. |

Le buzzer et l'indicateur lumineux du prototype actuel peuvent rester comme retour local, à condition d'évaluer leur utilité et leur consommation. Une interface web peut également recevoir un fichier exporté localement avant l'intégration d'une radio.

## Flux d'un incident

1. **Mesurer** : le capteur inertiel collecte les échantillons utiles. Un algorithme distingue une inclinaison soutenue, un choc bref et une manipulation normale. Les seuils sont configurables, puis calibrés avec des essais représentatifs.
2. **Horodater** : l'appareil associe l'événement à son horloge et conserve l'état de synchronisation de cette horloge. Une heure non synchronisée doit être signalée dans le journal.
3. **Enregistrer** : l'événement est écrit en mémoire non volatile avec un identifiant, son type, les mesures disponibles, les seuils actifs, l'état de la batterie et le contexte de position. Une coupure de réseau ne doit pas supprimer l'historique.
4. **Synchroniser** : la liaison transmet les événements quand elle existe. À défaut, un export local ou une synchronisation différée permet de récupérer le journal. Les doublons sont évités par l'identifiant stable de l'événement.
5. **Visualiser** : la carte et la chronologie affichent la source de chaque donnée et l'heure de dernière mise à jour. Un rapport de trajet doit pouvoir exposer les événements et leurs limites de précision.

## Règle de localisation

Un récepteur GNSS peut ne fournir aucun fix exploitable, notamment à l'intérieur d'un bâtiment ou d'un conteneur. La carte doit conserver cette incertitude :

| Affichage | Condition | Ce que cela signifie |
| --- | --- | --- |
| **Position mesurée** | Fix valide associé à l'instant de l'incident selon une fenêtre temporelle et un critère de qualité à définir. | Position observée par le dispositif ; afficher l'heure, la source et l'incertitude fournie. |
| **Dernière position connue** | Pas de fix valable pour l'incident, mais un fix antérieur existe. | Repère historique uniquement ; afficher l'âge du fix et éviter un marqueur présenté comme lieu du choc. |
| **Position indisponible** | Aucun fix exploitable. | L'événement reste dans la chronologie sans point sur la carte. |

Une position interpolée à partir du trajet pourrait être ajoutée plus tard, mais elle devra porter l'étiquette **estimation** et rester visuellement distincte d'une mesure. Le système ne prétend pas déterminer « exactement où » un choc s'est produit si le capteur n'a pas acquis de position à ce moment.

## Contrat de données de la démonstration

Le tableau de bord importe un fichier JSON de version 1 suivant le modèle de [`web/src/demo-trip.json`](../web/src/demo-trip.json). L'exemple ci-dessous reprend les champs utiles. Il ne correspond pas à une sortie du sketch Arduino actuel.

```json
{
  "schemaVersion": 1,
  "trip": {
    "id": "TA-2048",
    "name": "Transport optique de précision",
    "startedAt": "2026-09-18T06:30:00Z",
    "endedAt": "2026-09-18T15:42:00Z",
    "route": [[48.8566, 2.3522], [45.764, 4.8357]],
    "lastPosition": { "lat": 45.764, "lon": 4.8357, "capturedAt": "2026-09-18T15:39:00Z", "accuracyM": 16 }
  },
  "events": [{
    "id": "EV-003",
    "type": "tilt",
    "severity": "medium",
    "occurredAt": "2026-09-18T11:06:00Z",
    "title": "Basculement prolongé",
    "detail": "Angle maximal simulé : 47° pendant 12 s",
    "value": 47,
    "unit": "°",
    "location": { "status": "last_known", "lat": 47.022, "lon": 4.838, "capturedAt": "2026-09-18T10:54:00Z", "accuracyM": 32 }
  }]
}
```

Les valeurs sont **fictives**. `value` représente ici des mesures simulées et ne qualifie pas les dommages subis. `location.status` vaut `measured`, `last_known` ou `unavailable`. Pour `measured`, `capturedAt` doit égaler `occurredAt` dans cette démonstration ; pour `last_known`, le fix est antérieur. Pour `unavailable`, aucune coordonnée n'est exigée. Les timestamps sont en ISO 8601 et l'interface les affiche en heure de Paris. Le futur firmware devra préciser la synchronisation de son horloge avant qu'un journal puisse être considéré comme une preuve temporelle fiable.

Le sketch Uno émet séparément des lignes JSON sur USB (`ready`, `tilt`, `alarm`, `reset`) avec `uptime_ms`, `count` et `threshold`. Ce temps relatif depuis le démarrage ne peut pas être converti en date ou en position sans dispositif supplémentaire. L'import de ce flux brut dans la carte n'est donc pas proposé.

## Interfaces proposées

- **Vue flotte** : état des balises, dernier contact, batterie et nombre d'incidents ouverts.
- **Vue trajet** : carte, étapes et chronologie synchronisées. Les marqueurs différencient mesures, dernières positions connues et estimations.
- **Fiche incident** : type, heure, mesure, seuil appliqué, qualité de l'horloge, état de la position et contexte autour de l'événement.
- **Rapport exportable** : résumé et journal détaillé, avec les avertissements de qualité des données pertinents.

## Chemin de réalisation

1. **Expérience et données** : interface de démonstration avec trajets fictifs clairement identifiés, contrat de données et filtres d'incidents.
2. **Journal matériel** : capteur inertiel adapté, horloge et stockage local ; tests de secousses, inclinaisons, faux positifs et coupures d'alimentation.
3. **Localisation** : ajout du GNSS, journal des fixes et règle de qualification de position testée en intérieur et en extérieur.
4. **Connexion et boîtier** : choix de la liaison selon la couverture et le coût, autonomie mesurée, fixation réutilisable, essais de transport.

## Critères de validation avant toute promesse commerciale

- Comparer les détections à des essais contrôlés et documenter faux positifs et événements manqués.
- Vérifier que le journal survit à une coupure d'alimentation et que la synchronisation ne crée pas de doublons.
- Mesurer l'autonomie sur plusieurs profils de fréquence d'échantillonnage et de transmission.
- Vérifier que l'interface ne place jamais un incident sur la carte sans indiquer si le point est mesuré, historique ou estimé.
- Faire mesurer les dimensions, tolérances, sécurité électrique et conformité radio du boîtier final avant fabrication.

Le jaune reprend le langage visuel du logo existant. Les plans CAO décrivent une étude de boîtier et d'implantation de la carte TA-MB-01. Les dimensions, l'implantation réelle des circuits, les performances et les éventuelles revendications de propriété intellectuelle demanderont conception et vérification supplémentaires.

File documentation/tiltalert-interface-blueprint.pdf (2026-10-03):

1

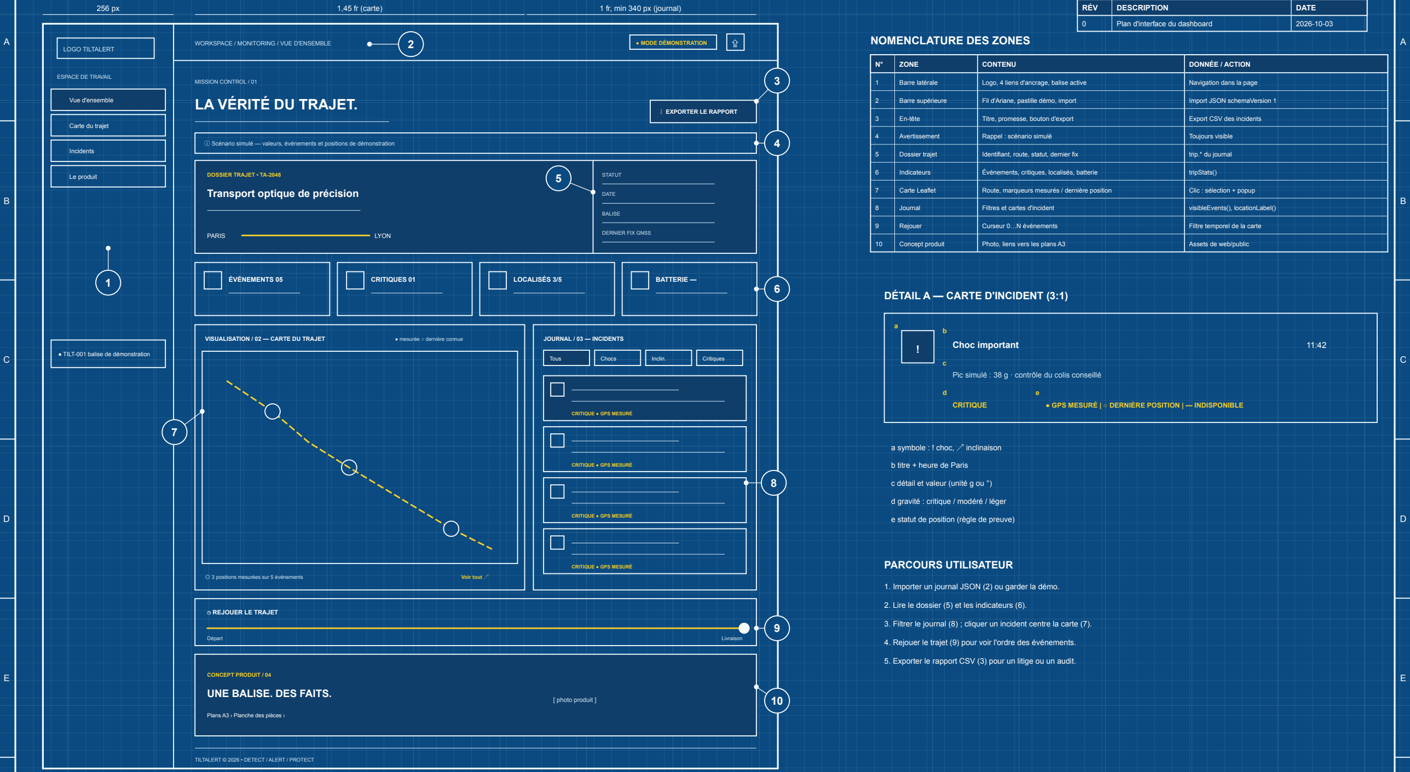
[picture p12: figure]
RÉV; DESCRIPTION; DATE; Plan d'interface du dashboard; LOGO TILTALERT; ESPACE DE TRAVAIL; Vue d'ensemble; Carte du trajet; Incidents; Le produit; ● TILT-001 balise de démonstration; MISSION CONTROL / 01; DOSSIER TRAJET • TA-2048 Transport optique de précision; PARIS; LYON; STATUT; BALISE; DERNIER FIX GNSS; ÉVÉNEMENTS 05; CRITIQUES 01; LOCALISÉS 3/5; BATTERIE —; JOURNAL / 03 — INCIDENTS; Tous; Chocs; Inclin.; Critiques; CRITIQUE ● GPS MESURÉ; ◷ REJOUER LE TRAJET; Départ; Livraison; CONCEPT PRODUIT / 04 UNE BALISE. DES FAITS.; Plans A3 › Planche des pièces ›; [ photo produit ]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
F | F
TILTALERT / TRACE | ÉTUDE CONCEPTUELLE — COTES PROVISOIRES — NE PAS FABRIQUER SANS REVUE

## NOTES GÉNÉRALES

1. Zones et libellés tirés de web/src/main.js ; largeurs et grilles de web/src/style.css.
2. Points de rupture CSS : 1250 px, 930 px, 620 px (empilement des panneaux sur mobile).
3. Données de démonstration (web/src/demo-trip.json) ; aucune mesure réelle affichée.
4. Règle de preuve : un point n'est jamais présenté comme mesuré s'il vient d'un fix antérieur.

# INTERFACE — TABLEAU DE BORD

### TiltAlert — centre de suivi web (web/), vue bureau 1440 px

N° PLAN

## TA-UI-01

ÉCHELLE

## ≈ 0,15 mm / px

RÉV
0

FEUILLE
1 / 1
DESSINÉ : M. ABAAQIL | DATE : 2026-10-03 | MATIÈRE : —
WORKSPACE / MONITORING / VUE D'ENSEMBLE | ● MODE DÉMONSTRATION | ⇪
LA VÉRITÉ DU TRAJET. | ⇩ EXPORTER LE RAPPORT

ⓘ Scénario simulé — valeurs, événements et positions de démonstration

VISUALISATION / 02 — CARTE DU TRAJET | ● mesurée ○ dernière connue
◎ 3 positions mesurées sur 5 événements | Voir tout ↗

TILTALERT © 2026 • DETECT / ALERT / PROTECT

256 px | 1,45 fr (carte) | 1 fr, min 340 px (journal)
1 | Barre latérale | Logo, 4 liens d'ancrage, balise active | Navigation dans la page
7 | Carte Leaflet | Route, marqueurs mesurés / dernière position | Clic : sélection + popup
10 | Concept produit | Photo, liens vers les plans A3 | Assets de web/public

Pic simulé : 38 g · contrôle du colis conseillé

CRITIQUE | ● GPS MESURÉ | ○ DERNIÈRE POSITION | — INDISPONIBLE
1. Importer un journal JSON (2) ou garder la démo.
2. Lire le dossier (5) et les indicateurs (6).
3. Filtrer le journal (8) ; cliquer un incident centre la carte (7).
4. Rejouer le trajet (9) pour voir l'ordre des événements.
5. Exporter le rapport CSV (3) pour un litige ou un audit.

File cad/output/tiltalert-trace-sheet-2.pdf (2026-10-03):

1

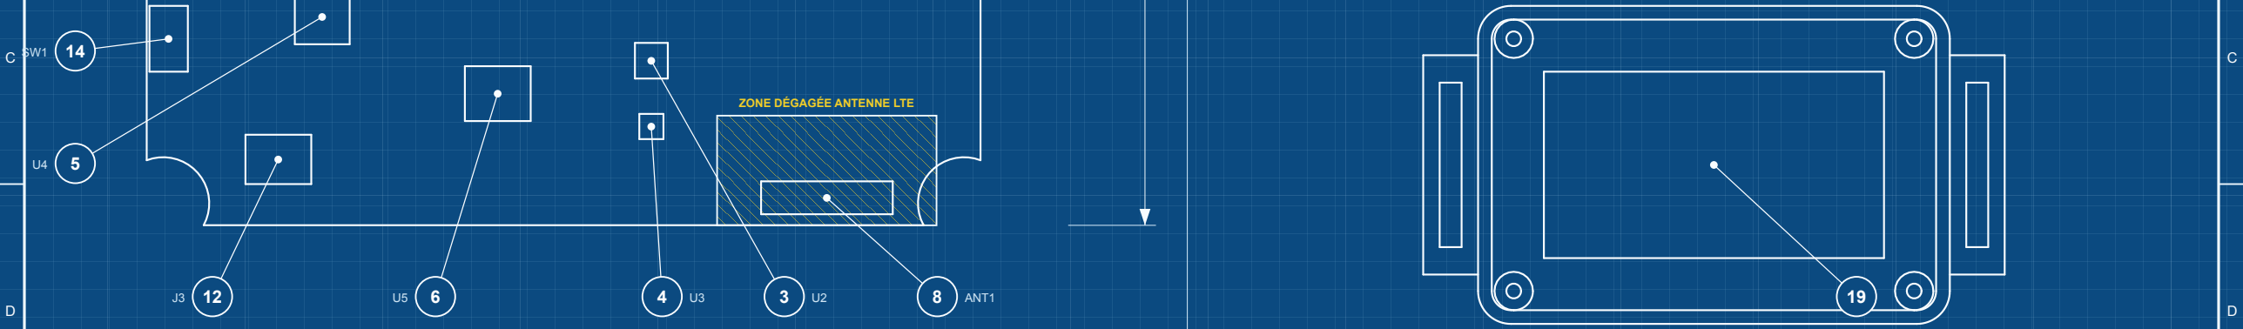
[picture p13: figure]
ZONE DÉGAGÉE ANTENNE LTE; 8 ANT1

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
A | A
B | B
E | E
F | F
TILTALERT / TRACE | ÉTUDE CONCEPTUELLE — COTES PROVISOIRES — NE PAS FABRIQUER SANS REVUE
RÉV | DESCRIPTION | DATE
0 | Carte nRF9151 + boîtier 86 × 58 | 2026-10-03

### NOTES GÉNÉRALES

1. Cotes en mm. Projection 3e dièdre. Tolérances générales à définir (proposé ISO 2768-m).
2. Contours des cartes : données fabricant/distributeur citées dans hardware/trace-v2/netlist.json.
3. Hauteurs de composants, connecteurs et positions de prises : gabarits indicatifs à mesurer.
4. Géométrie et plans générés par cad/generate.py (build123d 0.13.0) ; contrôles --check.

## CARTE TA-MB-01 ET IMPLANTATION

TiltAlert V2 — balise de suivi de chocs, carte TA-MB-01 (nRF9151)

N° PLAN

### TA-TR-GA-02

ÉCHELLE

### 2:1 (carte), 1:1

RÉV
0

FEUILLE
2 / 4
DESSINÉ : M. ABAAQIL | DATE : 2026-10-03 | MATIÈRE : à définir
U1 | 2

### 7 U6

### 9 ANT2

J1 | 10
BZ1 | 16 | 11 J2
D1 | 15
Q1 | 17 | D2 | 18 | 13 J4

76

50

### 01 CARTE TA-MB-01 — FACE COMPOSANTS / 2:1

Épaisseur 1 • 4 encoches R4.2 aux bossages • face supérieure à Z = 10

### CAPOT / FACE INTÉRIEURE / 1:1

Ø3.4 guide de lumière LP1 • 3 évents Ø1.5 buzzer • zone GNSS sans métal

### BASE + BT1 SUR MOUSSE (CARTE RETIRÉE) / 1:1

### RÈGLES D'IMPLANTATION

- ANT1 en bord de carte, zone dégagée sans cuivre ni composant (contrôlée).
- ANT2 face au capot polymère ; aucun métal au-dessus.
- U2/U3 près du centre de la carte, fixée par 4 points rigides.
- Batterie sous la carte : vérifier l'accord des antennes.
- J1 et SW1 alignés sur les ouvertures de la paroi -X (contrôlé).

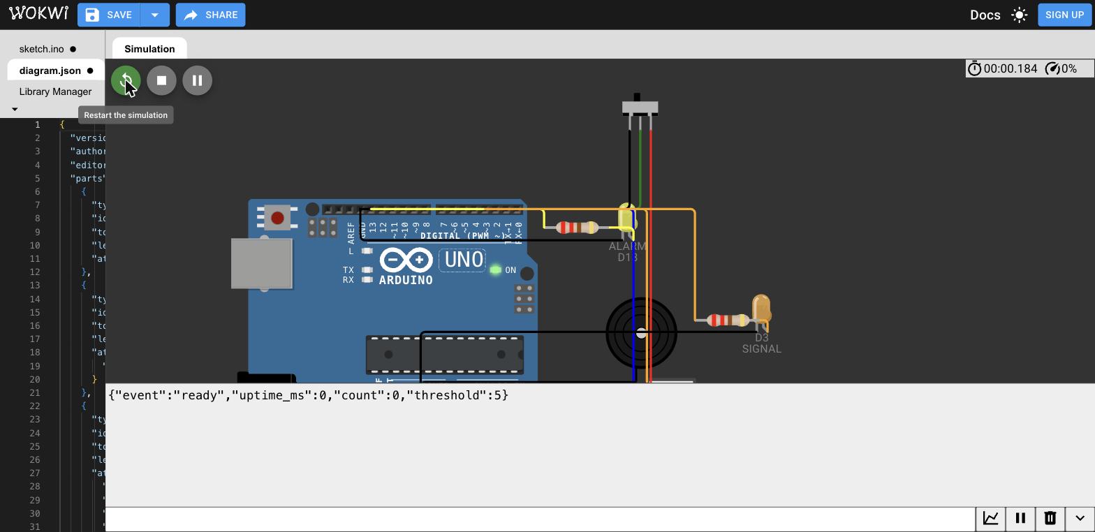
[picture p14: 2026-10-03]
simulation/captures/wokwi-ready.jpg

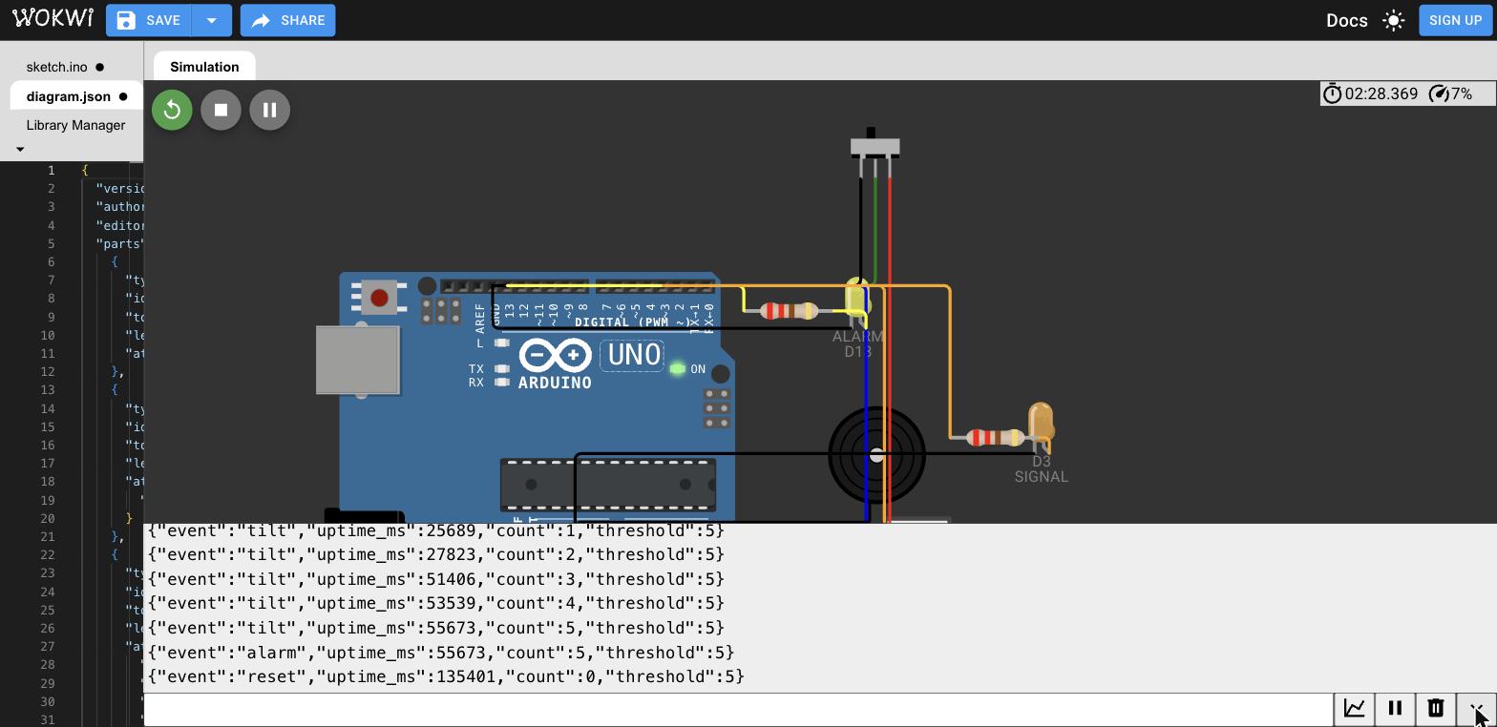
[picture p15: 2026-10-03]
simulation/captures/wokwi-serial-log.jpg

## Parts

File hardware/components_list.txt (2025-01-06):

1x Arduino Uno
1x Breadboard
1x Capteur KY-020 (inclinaison)
1x Buzzer KY-012
1x Bouton poussoir KY-004
1x LED rouge
1x Résistance 220 Ω
1x Résistance 10 kΩ
Jumper Wires

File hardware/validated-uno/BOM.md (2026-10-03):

# Nomenclature — TiltAlert Uno corrigé

| Réf. | Composant | Quantité / valeur | Note |
|---|---|---|---|
| U1 | Arduino Uno R3 | 1 | Sorties D3 et D13; entrées D2 et D12 |
| S1 | Contact d'inclinaison NO | 1 | KY-020 ou contact équivalent; fermé = HIGH sur D2 |
| R1 | Résistance | 10 kΩ | Pull-down externe de D2; 0,25 W |
| S2 | Bouton poussoir NO | 1 | Acquittement; D12 utilise INPUT_PULLUP |
| R2 | Résistance | 220 Ω | Limitation du courant de la LED externe; 0,25 W |
| D1 | LED rouge externe | 1 | Anode vers R2; cathode vers GND |
| BZ1 | Buzzer actif 5 V | 1 | Entrée signal compatible 5 V, faible courant; vérifier la fiche du module choisi |

Ajouter une breadboard, des fils de liaison et un câble USB pour le montage d'essai.
Le buzzer actif doit accepter un signal logique de 5 V et présenter une entrée de commande à faible courant.
La valeur de 220 Ω donne environ 10–15 mA pour une LED rouge typique; vérifier la LED et la limite de la broche.

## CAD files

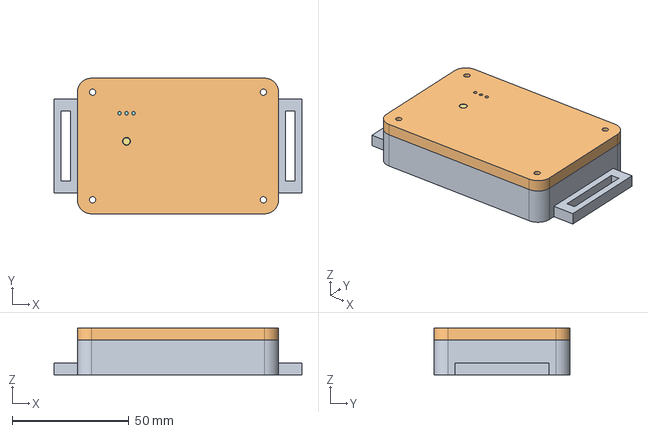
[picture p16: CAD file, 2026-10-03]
cad/output/tiltalert-trace-assembly.step
106.0 x 58.0 x 20.0 mm

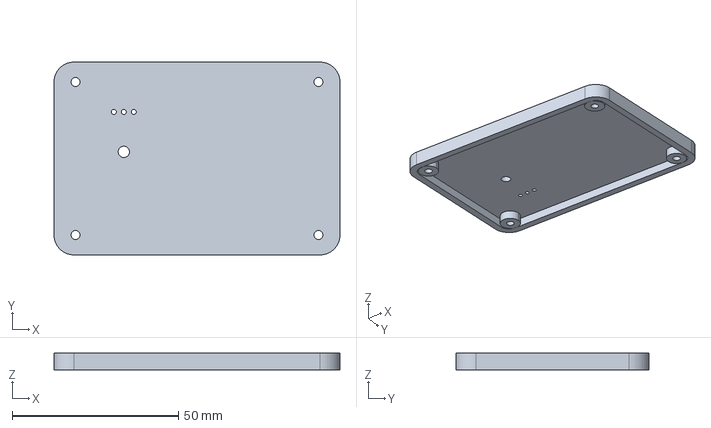
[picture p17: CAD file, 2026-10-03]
cad/output/tiltalert-trace-lid.step
86.0 x 58.0 x 5.00 mm

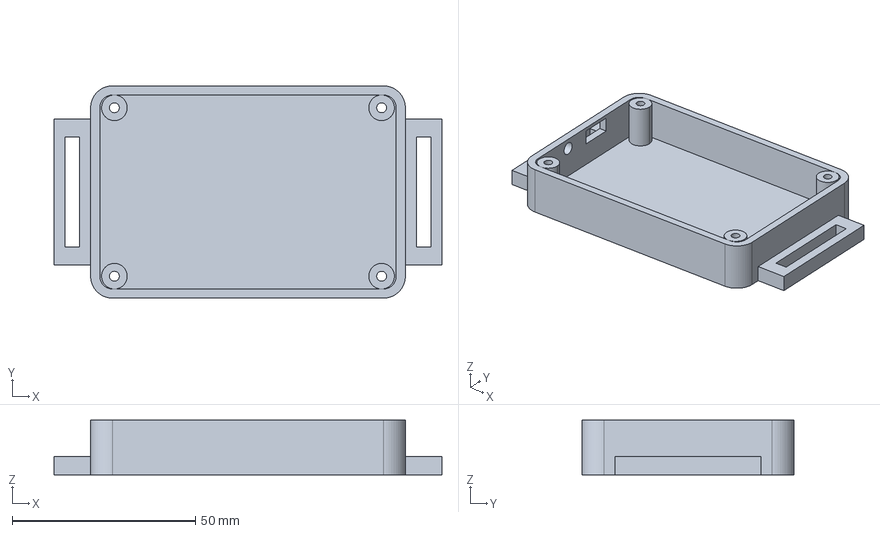
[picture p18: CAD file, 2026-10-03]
cad/output/tiltalert-trace-base.step
106.0 x 58.0 x 15.0 mm

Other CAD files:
cad/output/tiltalert-trace-base.stl
cad/output/tiltalert-trace-lid.stl

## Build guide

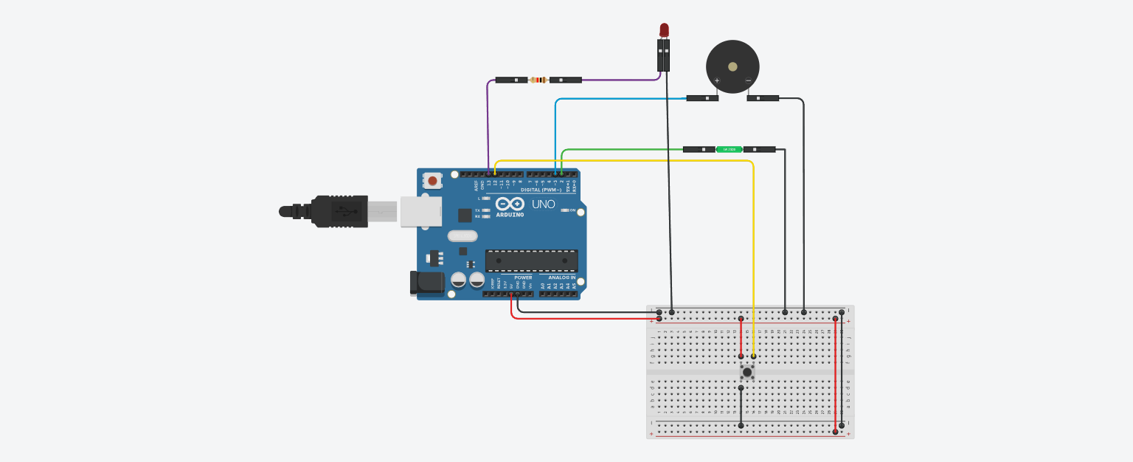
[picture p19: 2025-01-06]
hardware/wiring_diagram.png

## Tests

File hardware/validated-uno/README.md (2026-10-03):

# Circuit Uno corrigé — TiltAlert

Ce dossier décrit **le prototype Arduino Uno actuel**, avec une netlist explicite, un schéma électrique A3, une [implantation physique sur breadboard](./tiltalert-uno-physical.svg) et une nomenclature. Le [schéma SVG](./tiltalert-uno-electrical.svg) et le [PDF de deux pages](./tiltalert-uno-electrical.pdf) sont générés par `generate.py` depuis `netlist.json` ; l'implantation vient de la table de placement de `physical.py`. Le dessin est schématique, sans échelle physique.

## Générer et contrôler

```bash
python3 hardware/validated-uno/generate.py
```

La génération vérifie toutes les affectations de bornes, la topologie attendue, l'unicité des bornes, et la séparation de `+5V` et `GND`. Elle reconstruit aussi les nœuds électriques de la breadboard (bandes a–e / f–j, rails, jumpers) et refuse l'implantation si un réseau est coupé, si deux réseaux se touchent ou si deux pattes partagent un trou. `rsvg-convert` est nécessaire pour le PDF. Ce contrôle statique ne remplace pas les essais sur carte ni la vérification électrique d'un montage physique.

## Câblage

| Réseau | Bornes |
|---|---|
| `+5V` | Uno 5V, contact d'inclinaison S1-1, buzzer actif BZ1-VCC |
| `GND` | Uno GND, R1-2, bouton S2-2, LED D1 cathode, buzzer BZ1-GND |
| `TILT_D2` | Uno D2, S1-2, R1-1 |
| `RESET_D12` | Uno D12, S2-1 |
| `ALARM_D13` | Uno D13, R2-1 |
| `LED_A` | R2-2, anode LED D1 |
| `BUZZ_D3` | Uno D3, entrée SIG du buzzer actif BZ1 |

Le code utilise `INPUT` sur D2 : **R1 (10 kΩ) est indispensable avec un contact nu** pour définir LOW quand S1 est ouvert. La fermeture de S1 applique HIGH à D2. D12 utilise `INPUT_PULLUP`; le bouton relie D12 à la masse lorsqu'il est pressé. La LED **externe** a sa propre résistance R2 de 220 Ω. La LED intégrée de l'Uno, également pilotée par D13, peut s'allumer en parallèle.

Le sketch applique un niveau HIGH continu à D3 pendant l'alarme. Il faut donc un **buzzer actif** à entrée de commande logique 5 V et faible courant. Une simple pastille piezo passive à deux bornes n'émettra pas une tonalité continue avec ce code. Si un module actif consomme plus que ce que la sortie D3 peut fournir ou n'a pas d'entrée SIG, prévoir un étage transistor adapté avant montage; le présent schéma suppose une entrée SIG à faible courant.

Le fichier historique `hardware/wiring_diagram.brd` relie par erreur la broche **5V** de l'Uno au réseau **GND** et représente un piezo passif. Ne pas le reproduire comme câblage validé. Le contact simulé représente uniquement l'état ouvert/fermé du KY-020; il ne démontre ni sensibilité aux chocs, ni accélération, ni position.

**À vérifier sur le module KY-020 reçu.** Certains modules portent une résistance embarquée. Mesurer au multimètre, module hors tension, la résistance entre S et +V puis entre S et GND. Une résistance de rappel vers +V combinée à R1 formerait un diviseur et laisserait D2 à un niveau intermédiaire : dans ce cas seulement, retirer R1 ou utiliser un contact d'inclinaison nu, comme sur l'implantation. Une résistance vers GND se met simplement en parallèle de R1 sans gêner la lecture.

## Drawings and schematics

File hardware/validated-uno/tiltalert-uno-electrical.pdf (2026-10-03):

TILTALERT / SCHÉMA ÉLECTRIQUE | UNO · REV A

## 01 ENTRÉE INCLINAISON

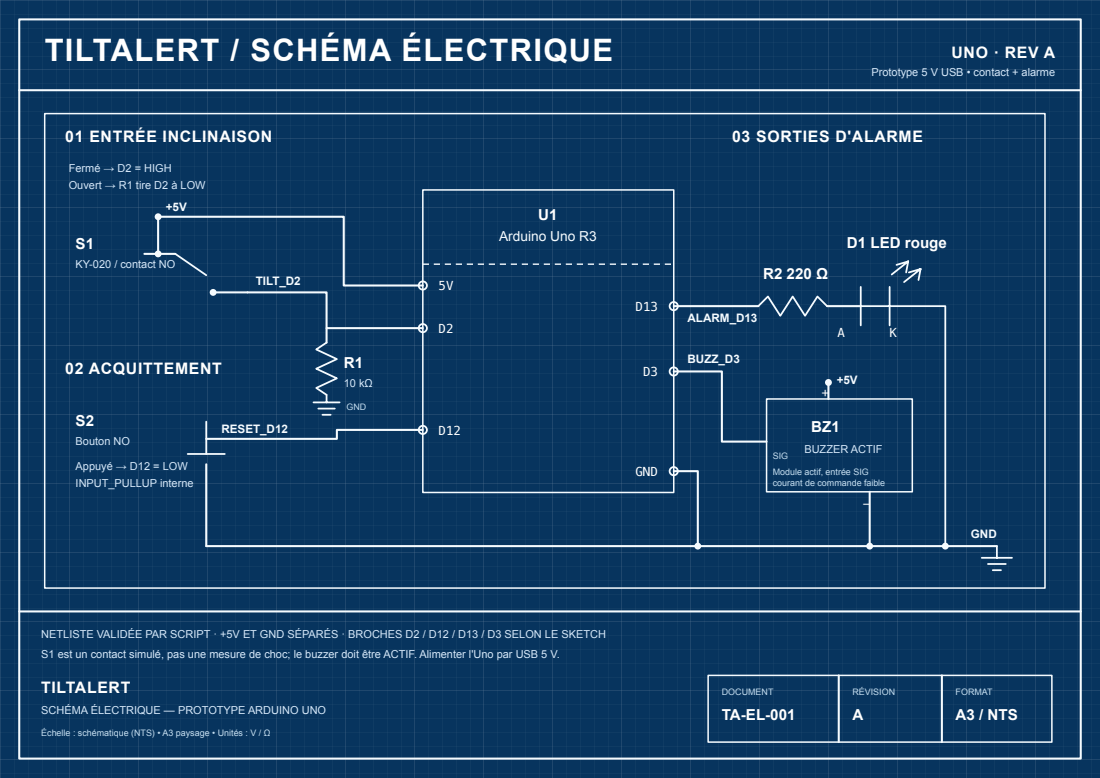
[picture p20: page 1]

Prototype 5 V USB • contact + alarme

SIG
Module actif, entrée SIG
courant de commande faible

NETLISTE VALIDÉE PAR SCRIPT · +5V ET GND SÉPARÉS · BROCHES D2 / D12 / D13 / D3 SELON LE SKETCH
S1 est un contact simulé, pas une mesure de choc; le buzzer doit être ACTIF. Alimenter l'Uno par USB 5 V.
TILTALERT

SCHÉMA ÉLECTRIQUE — PROTOTYPE ARDUINO UNO

Échelle : schématique (NTS) • A3 paysage • Unités : V / Ω

TILTALERT / IMPLANTATION PHYSIQUE | UNO · REV A

## LISTE DES LIAISONS

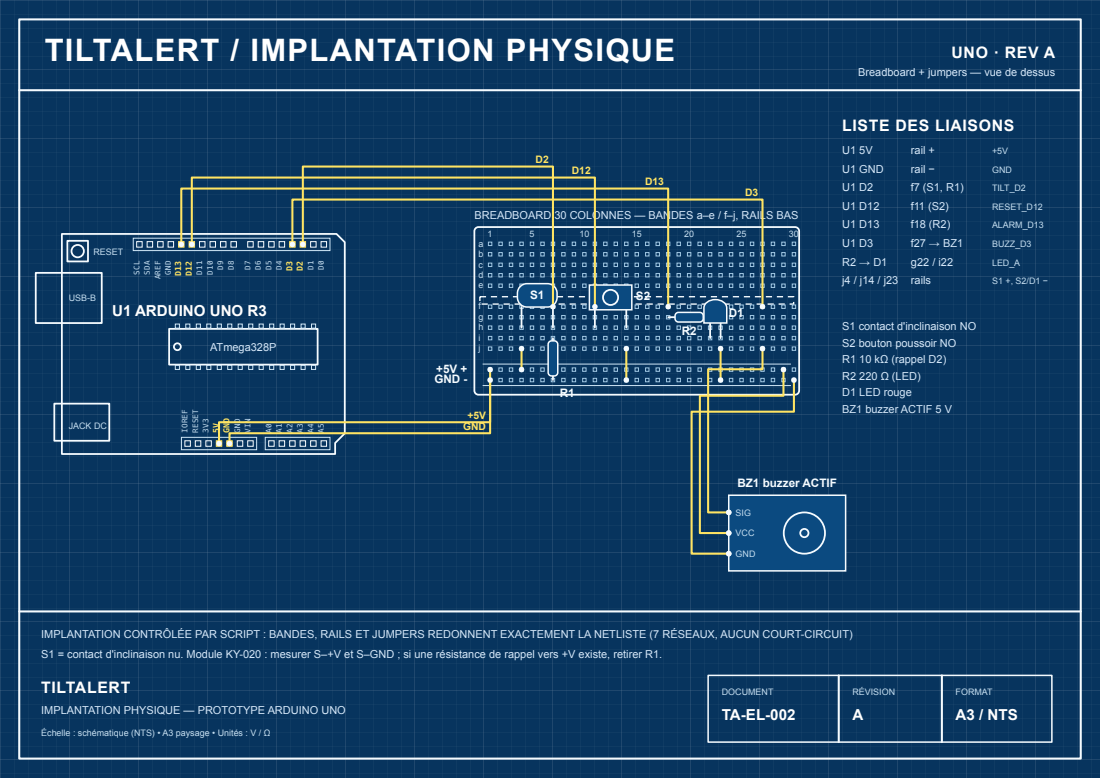
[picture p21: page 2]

Breadboard + jumpers — vue de dessus

BREADBOARD 30 COLONNES — BANDES a–e / f–j, RAILS BAS

IMPLANTATION CONTRÔLÉE PAR SCRIPT : BANDES, RAILS ET JUMPERS REDONNENT EXACTEMENT LA NETLISTE (7 RÉSEAUX, AUCUN COURT-CIRCUIT)
S1 = contact d'inclinaison nu. Module KY-020 : mesurer S–+V et S–GND ; si une résistance de rappel vers +V existe, retirer R1.
TILTALERT

IMPLANTATION PHYSIQUE — PROTOTYPE ARDUINO UNO

Échelle : schématique (NTS) • A3 paysage • Unités : V / Ω

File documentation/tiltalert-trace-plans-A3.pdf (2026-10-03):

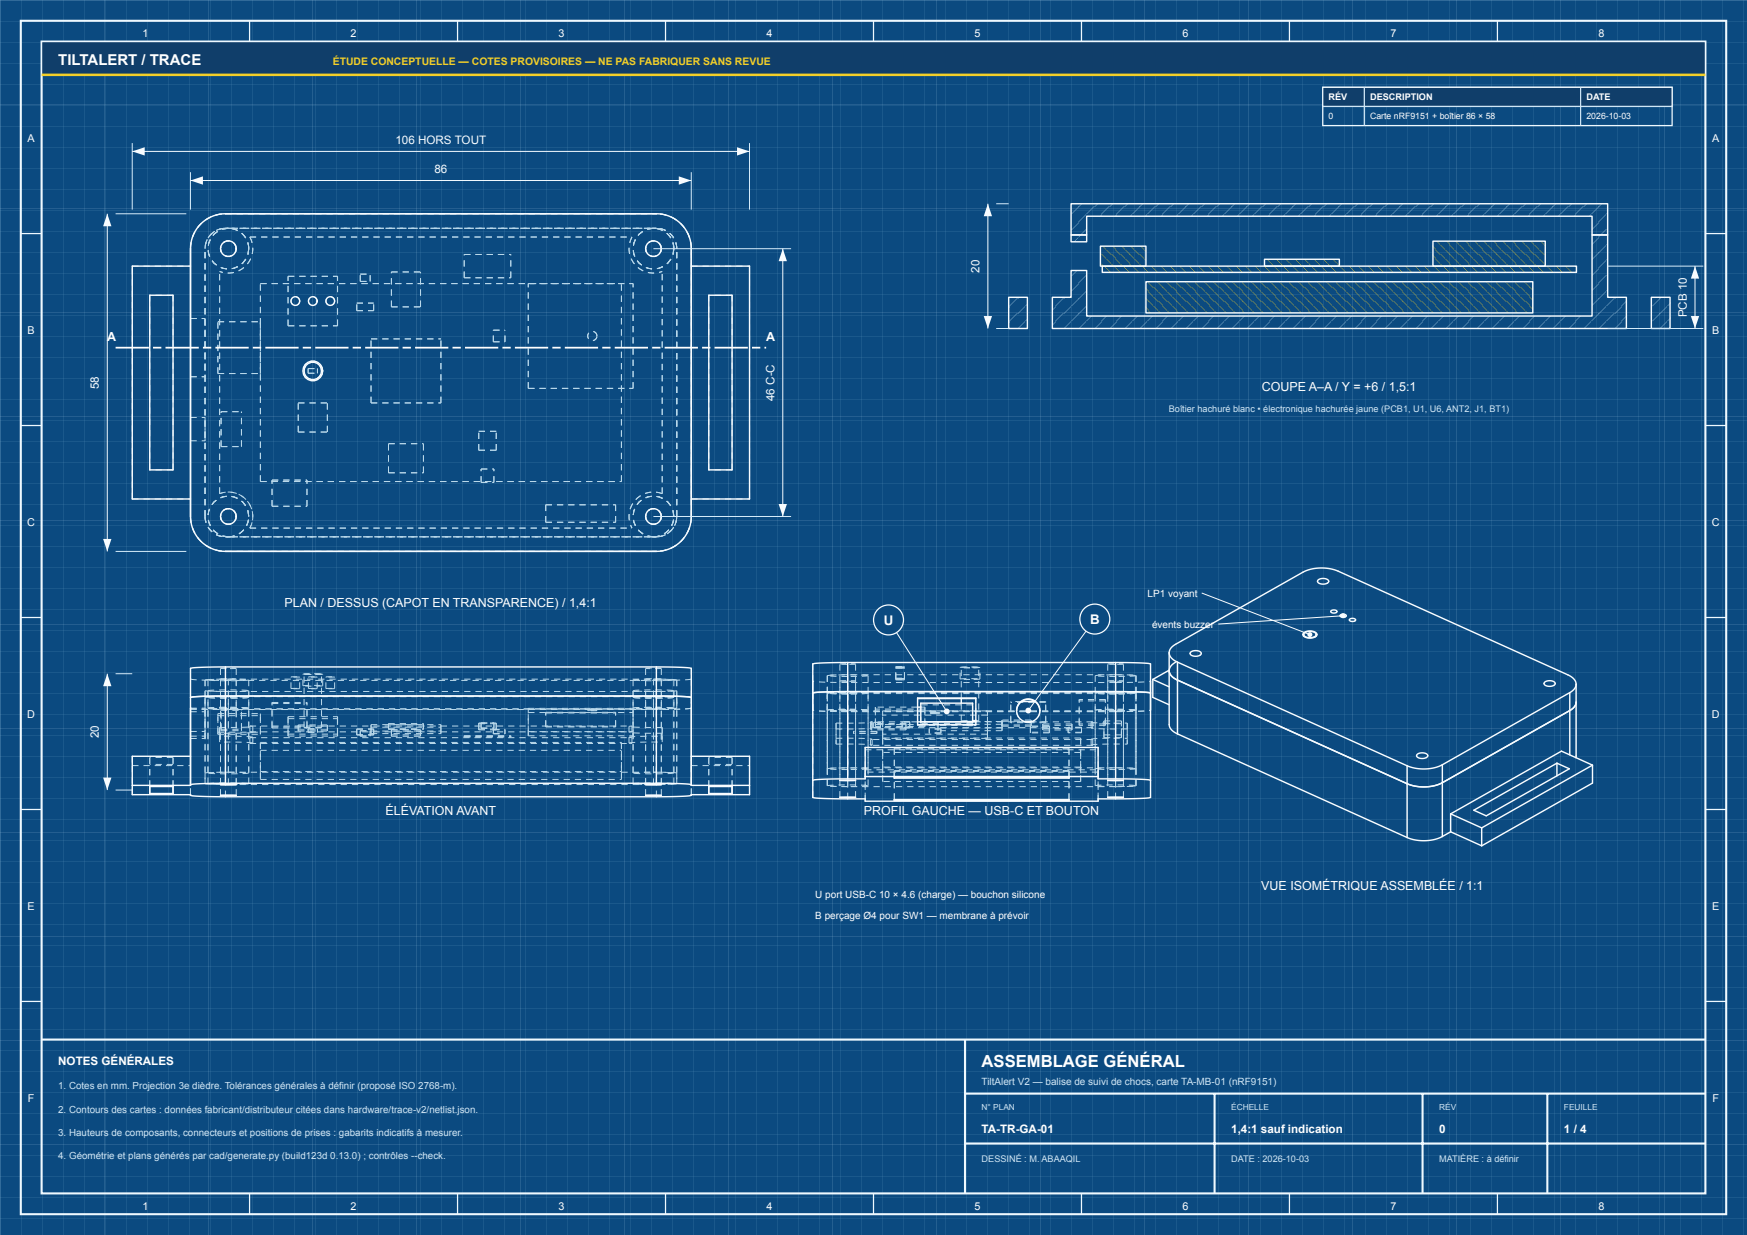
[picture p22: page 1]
TILTALERT / TRACE; ÉTUDE CONCEPTUELLE — COTES PROVISOIRES — NE PAS FABRIQUER SANS REVUE; RÉV; DESCRIPTION; DATE; Carte nRF9151 + boîtier 86 × 58; NOTES GÉNÉRALES; ASSEMBLAGE GÉNÉRAL; ÉCHELLE 1,4:1 sauf indication; RÉV 0; FEUILLE 1 / 4; DESSINÉ : M. ABAAQIL; DATE : 2026-10-03; MATIÈRE : à définir; 106 HORS TOUT; ÉLÉVATION AVANT; COUPE A–A / Y = +6 / 1,5:1; PCB 10; LP1 voyant; évents buzzer

Boîtier hachuré blanc • électronique hachurée jaune (PCB1, U1, U6, ANT2, J1, BT1)

PLAN / DESSUS (CAPOT EN TRANSPARENCE) / 1,4:1

PROFIL GAUCHE — USB-C ET BOUTON

VUE ISOMÉTRIQUE ASSEMBLÉE / 1:1

U port USB-C 10 × 4.6 (charge) — bouchon silicone
B perçage Ø4 pour SW1 — membrane à prévoir

1. Cotes en mm. Projection 3e dièdre. Tolérances générales à définir (proposé ISO 2768-m).
2. Contours des cartes : données fabricant/distributeur citées dans hardware/trace-v2/netlist.json.

TiltAlert V2 — balise de suivi de chocs, carte TA-MB-01 (nRF9151)

N° PLAN

3. Hauteurs de composants, connecteurs et positions de prises : gabarits indicatifs à mesurer.

4. Géométrie et plans générés par cad/generate.py (build123d 0.13.0) ; contrôles --check.

A | A
B | B

ZONE DÉGAGÉE ANTENNE LTE; 8 ANT1

E | E
0 | Carte nRF9151 + boîtier 86 × 58 | 2026-10-03

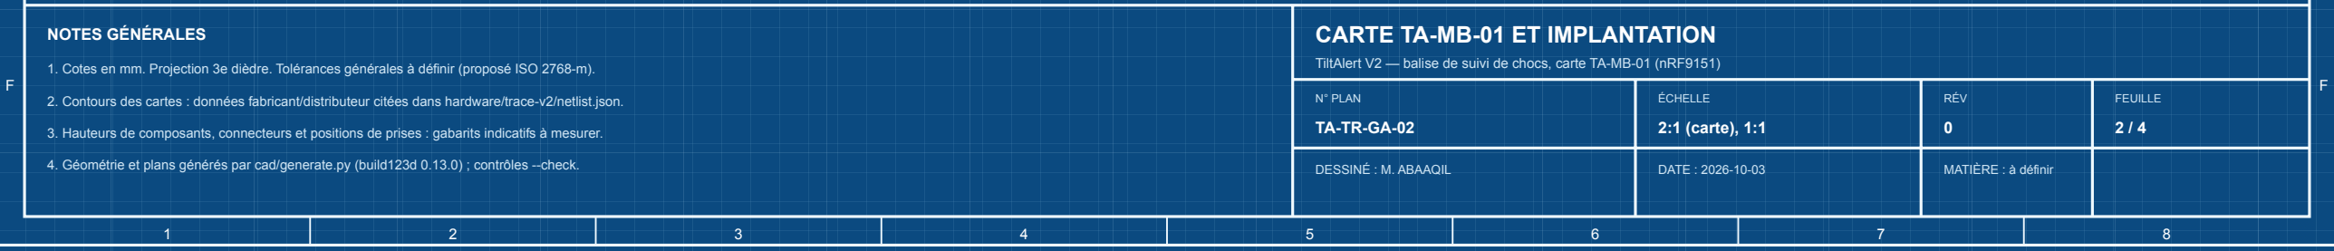
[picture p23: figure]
NOTES GÉNÉRALES; CARTE TA-MB-01 ET IMPLANTATION; N° PLAN TA-TR-GA-02; ÉCHELLE 2:1 (carte), 1:1; RÉV 0; FEUILLE 2 / 4

1. Cotes en mm. Projection 3e dièdre. Tolérances générales à définir (proposé ISO 2768-m).
2. Contours des cartes : données fabricant/distributeur citées dans hardware/trace-v2/netlist.json.

TiltAlert V2 — balise de suivi de chocs, carte TA-MB-01 (nRF9151)

U1 2

### 7 U6

### 9 ANT2

J1 | 10
BZ1 | 16 | 11 J2
D1 | 15
Q1 | 17 | D2 | 18 | 13 J4

76

50

### 01 CARTE TA-MB-01 — FACE COMPOSANTS / 2:1

Épaisseur 1 • 4 encoches R4.2 aux bossages • face supérieure à Z = 10

### CAPOT / FACE INTÉRIEURE / 1:1

Ø3.4 guide de lumière LP1 • 3 évents Ø1.5 buzzer • zone GNSS sans métal

### BASE + BT1 SUR MOUSSE (CARTE RETIRÉE) / 1:1

### RÈGLES D'IMPLANTATION

- ANT1 en bord de carte, zone dégagée sans cuivre ni composant (contrôlée).
- ANT2 face au capot polymère ; aucun métal au-dessus.
- U2/U3 près du centre de la carte, fixée par 4 points rigides.
- Batterie sous la carte : vérifier l'accord des antennes.
- J1 et SW1 alignés sur les ouvertures de la paroi -X (contrôlé).

2

10

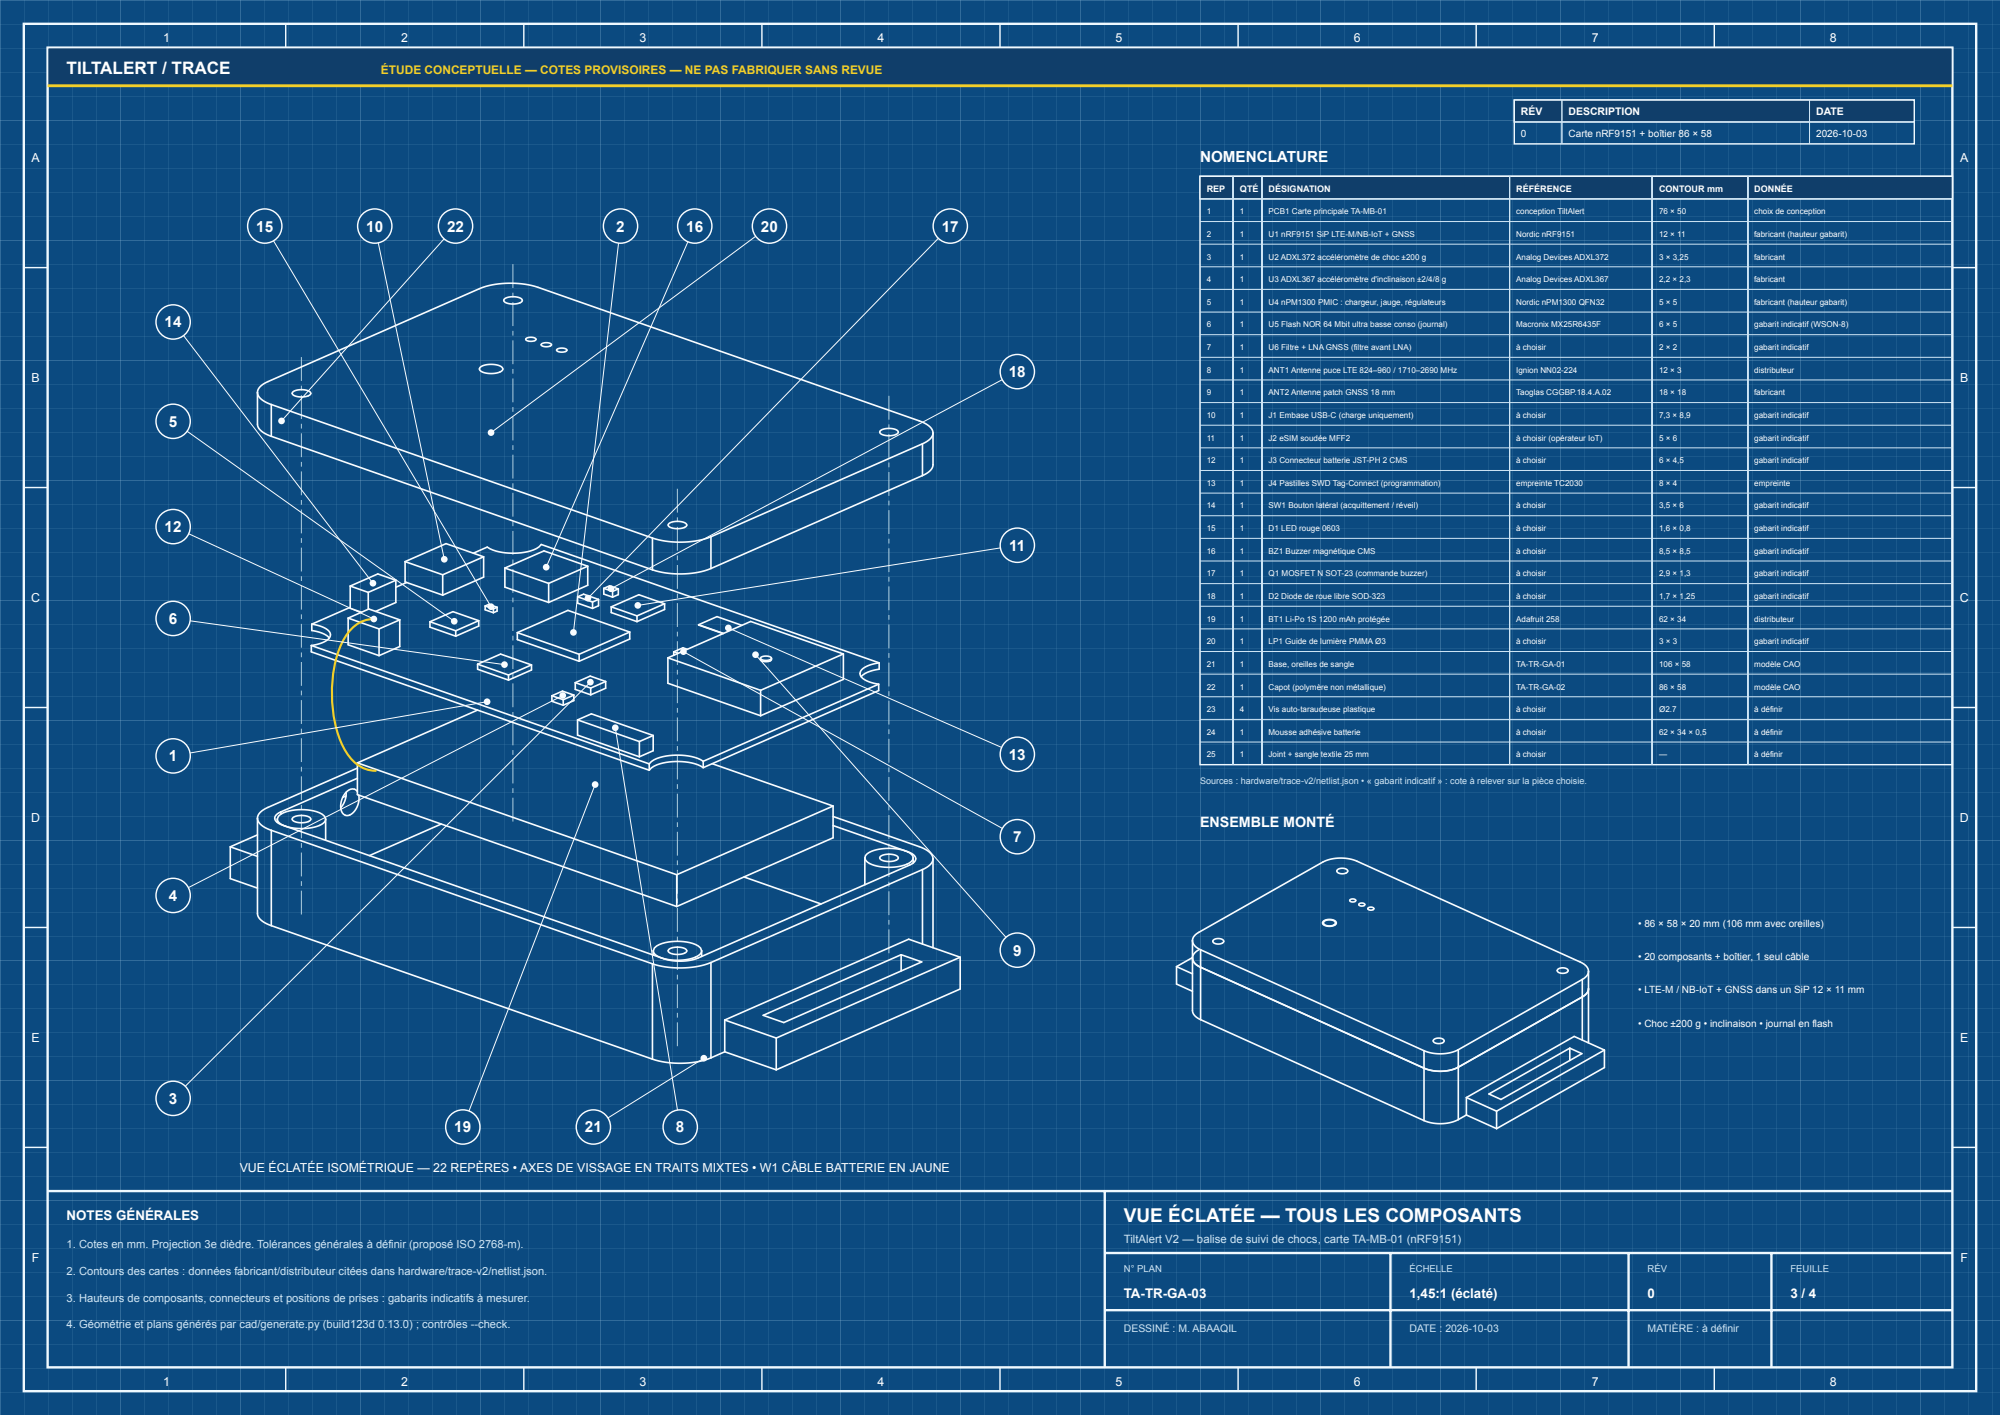
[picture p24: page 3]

Sources : hardware/trace-v2/netlist.json • « gabarit indicatif » : cote à relever sur la pièce choisie.

• 86 × 58 × 20 mm (106 mm avec oreilles)

• 20 composants + boîtier, 1 seul câble

• LTE-M / NB-IoT + GNSS dans un SiP 12 × 11 mm

• Choc ±200 g • inclinaison • journal en flash

VUE ÉCLATÉE ISOMÉTRIQUE — 22 REPÈRES • AXES DE VISSAGE EN TRAITS MIXTES • W1 CÂBLE BATTERIE EN JAUNE

VUE ÉCLATÉE — TOUS LES COMPOSANTS

1. Cotes en mm. Projection 3e dièdre. Tolérances générales à définir (proposé ISO 2768-m).
2. Contours des cartes : données fabricant/distributeur citées dans hardware/trace-v2/netlist.json.

TiltAlert V2 — balise de suivi de chocs, carte TA-MB-01 (nRF9151)

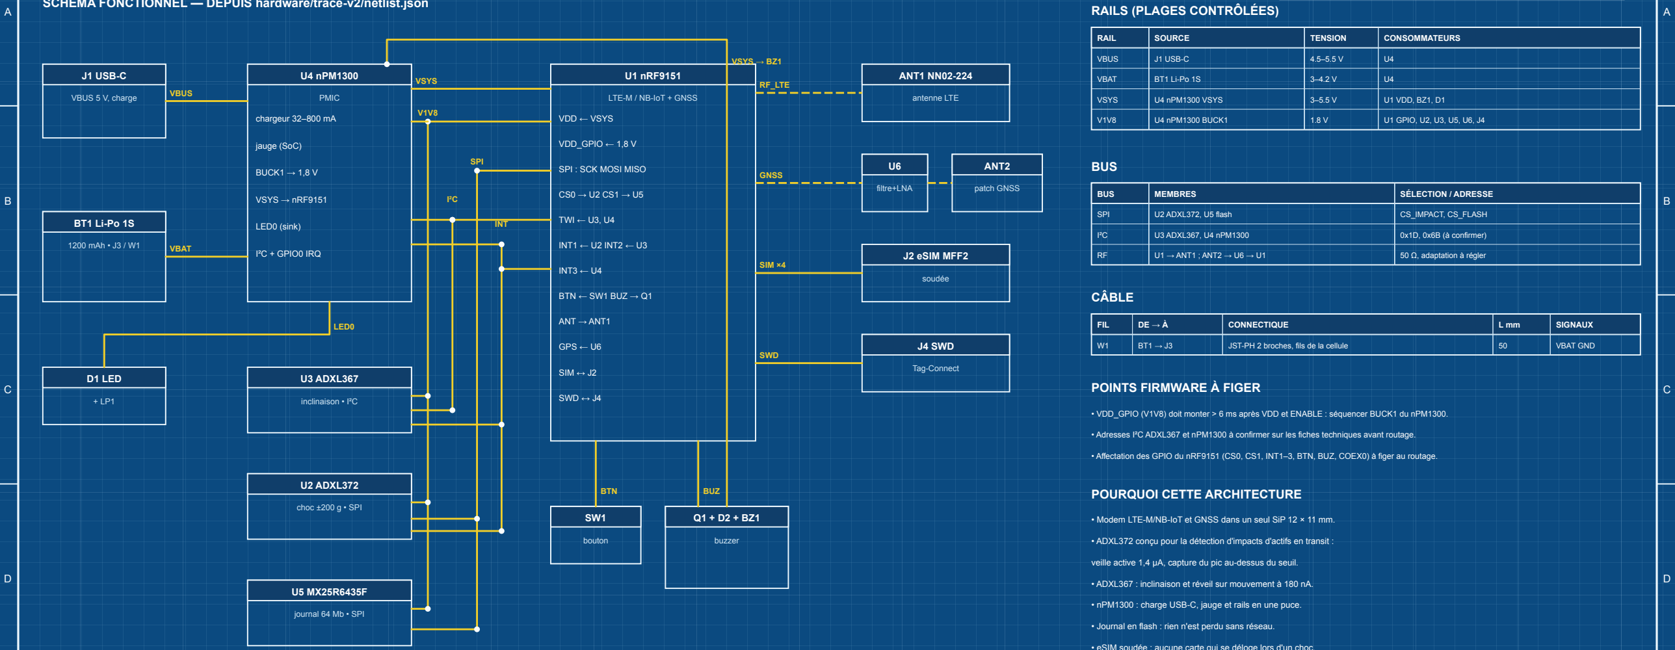
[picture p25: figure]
J1 USB-C; VBUS 5 V, charge; 1200 mAh • J3 / W1; U4 nPM1300; PMIC; chargeur 32–800 mA; jauge (SoC); BUCK1 → 1,8 V; VSYS → nRF9151; LED0 (sink); I²C + GPIO0 IRQ; U1 nRF9151; LTE-M / NB-IoT + GNSS; VDD ← VSYS; VDD_GPIO ← 1,8 V; SPI : SCK MOSI MISO; TWI ← U3, U4; INT1 ← U2 INT2 ← U3; INT3 ← U4; BTN ← SW1 BUZ → Q1; ANT → ANT1; GPS ← U6; SIM ↔ J2; SWD ↔ J4; ANT1 NN02-224; antenne LTE; filtre+LNA; ANT2; patch GNSS; J2 eSIM MFF2; soudée; J4 SWD; Tag-Connect; U3 ADXL367; inclinaison • I²C; U2 ADXL372; choc ±200 g • SPI; journal 64 Mb • SPI; bouton; buzzer; D1 LED; VBUS; VBAT; VSYS; VSYS → BZ1; LED0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

E | E
0 | Carte nRF9151 + boîtier 86 × 58 | 2026-10-03

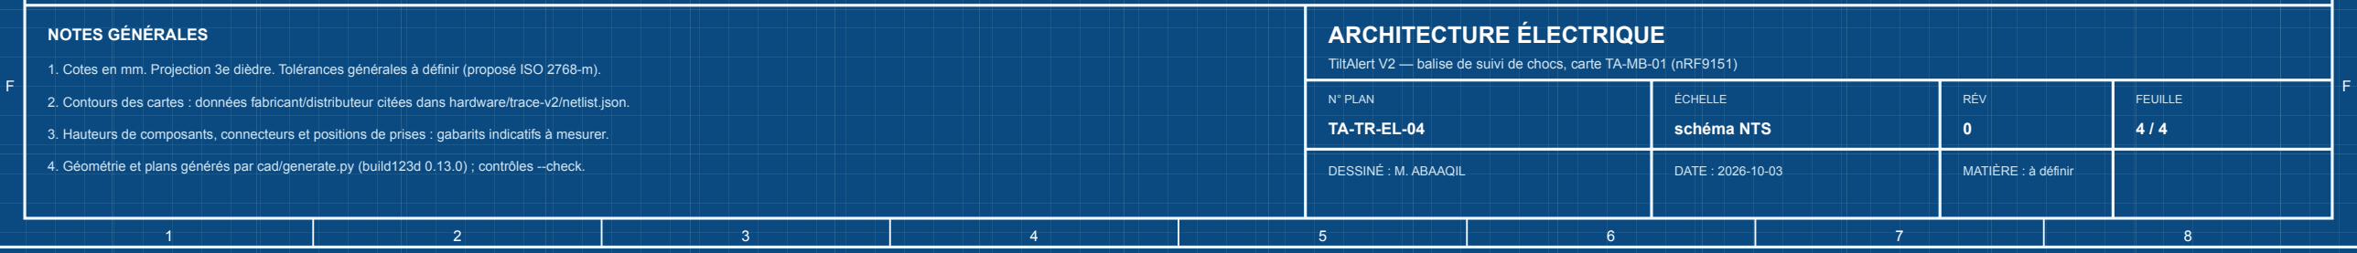
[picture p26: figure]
NOTES GÉNÉRALES; ARCHITECTURE ÉLECTRIQUE; N° PLAN TA-TR-EL-04; ÉCHELLE schéma NTS; RÉV 0; FEUILLE 4 / 4

1. Cotes en mm. Projection 3e dièdre. Tolérances générales à définir (proposé ISO 2768-m).
2. Contours des cartes : données fabricant/distributeur citées dans hardware/trace-v2/netlist.json.

TiltAlert V2 — balise de suivi de chocs, carte TA-MB-01 (nRF9151)
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

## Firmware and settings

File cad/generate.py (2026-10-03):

#!/usr/bin/env python3
"""Parametric enclosure, V2 electronics layout and A3 drawing set for TiltAlert.

All dimensions are millimetres.  Run with Python 3.12 and build123d 0.13.0.
The enclosure is a design study, not a measured or production-ready part.
Component outlines come from hardware/trace-v2/netlist.json; heights marked
"gabarit" there are indicative envelopes used for clearance checks.
"""

from __future__ import annotations

import argparse
import math
import shutil
from dataclasses import dataclass
from html import escape
from pathlib import Path
import subprocess

from build123d import (
    Align, Box, Cylinder, Compound, Plane, Pos, Rot, Shape,
    export_step, export_stl, fillet, section,
)

from drafting import balloon, dim_h, dim_v, line, rect, sheet_start, table, txt
from components import ANT1_KEEPOUT, build_parts, load_netlist, validate_netlist, wire_routes

MIN = (Align.CENTER, Align.CENTER, Align.MIN)


@dataclass(frozen=True)
class Dimensions:
    length: float = 86
    width: float = 58
    height: float = 20
    base_height: float = 15
    wall: float = 2.5
    floor: float = 2
    roof: float = 2
    corner_radius: float = 6
    screw_x: float = 36.5
    screw_y: float = 23
    boss_radius: float = 3.5
    screw_diameter: float = 2.7
    # External strap ears at both ends, so the strap never crosses the cavity.
    ear_length: float = 10
    ear_thickness: float = 5
    strap_slot_width: float = 4
    strap_slot_length: float = 30
    # Main board TA-MB-01, held above the battery.
    pcb_length: float = 76
    pcb_width: float = 50
    pcb_thickness: float = 1.0
    pcb_z: float = 9.0
    pcb_notch_gap: float = 0.7
    foam: float = 0.5
    battery_x: float = 0
    # Openings: USB-C and side button in the -X wall, light pipe and buzzer vents in the lid.
    usb_y: float = 6
    usb_width: float = 10
    usb_height: float = 4.6
    button_y: float = -8
    button_d: float = 4
    light_pipe_d: float = 3
    light_hole_d: float = 3.4
    vent_d: float = 1.5
    min_clearance: float = 0.2


D = Dimensions()
ROOT = Path(__file__).resolve().parent
REPO = ROOT.parent
OUT = ROOT / "output"
DATE = "2026-10-03"
SHEETS = 4


def rounded_box(length: float, width: float, height: float, z0: float, radius: float):
    solid = Pos(0, 0, z0) * Box(length, width, height, align=(Align.CENTER, Align.CENTER, Align.MIN))
    vertical = [e for e in solid.edges() if abs((e.end_point() - e.start_point()).Z) > height - 0.01]
    return fillet(vertical, radius)


def screw_centers(d: Dimensions):
    return [(x, y) for x in (-d.screw_x, d.screw_x) for y in (-d.screw_y, d.screw_y)]


def board_top(d: Dimensions):
    return d.pcb_z + d.pcb_thickness


def make_parts(d: Dimensions = D):
    from components import FLOORPLAN
    # Open topped base.  The cut extends through the top face.
    base = rounded_box(d.length, d.width, d.base_height, 0, d.corner_radius)
    cavity = rounded_box(d.length - 2*d.wall, d.width - 2*d.wall,
                         d.base_height - d.floor + 1, d.floor,
                         d.corner_radius - d.wall)
    base = base - cavity
    # Four coaxial pillars and through bores.  The same centers drive the lid.
    for x, y in screw_centers(d):
        base += Pos(x, y, d.floor) * Cylinder(d.boss_radius, d.base_height-d.floor, align=MIN)
    for x, y in screw_centers(d):
        base -= Pos(x, y, -1) * Cylinder(d.screw_diameter/2, d.base_height+2, align=MIN)
    # Two end ears carry the strap outside the electronics volume.
    for sx in (-1, 1):
        ear_x = sx * (d.length/2 + d.ear_length/2 - 1)
        ear = Pos(ear_x, 0, 0) * Box(d.ear_length + 2, d.strap_slot_length + 10, d.ear_thickness, align=MIN)
        ear -= Pos(ear_x + sx, 0, -1) * Box(d.strap_slot_width, d.strap_slot_length, d.ear_thickness + 2, align=MIN)
        base += ear
    # USB-C and button openings, aligned with J1 and SW1 on the board.
    top = board_top(d)
    base -= Pos(-d.length/2, d.usb_y, top + 1.6 - d.usb_height/2) * Box(
        3*d.wall, d.usb_width, d.usb_height, align=MIN)
    base -= Pos(-d.length/2, d.button_y, top + 1.75) * Rot(0, 90, 0) * Cylinder(d.button_d/2, 3*d.wall)

    # Cap is a separate hollow part.  Its four sleeves meet the base pillars.
    lid_height = d.height - d.base_height
    lid = rounded_box(d.length, d.width, lid_height, d.base_height, d.corner_radius)
    lid -= rounded_box(d.length - 2*d.wall, d.width - 2*d.wall,
                       lid_height-d.roof+0.1, d.base_height-0.1,
                       d.corner_radius-d.wall)
    for x, y in screw_centers(d):
        lid += Pos(x, y, d.base_height) * Cylinder(d.boss_radius, lid_height-d.roof, align=MIN)
    for x, y in screw_centers(d):
        lid -= Pos(x, y, d.base_height-1) * Cylinder(d.screw_diameter/2, lid_height+2, align=MIN)
    lx, ly = FLOORPLAN["D1"]
    lid -= Pos(lx, ly, d.base_height) * Cylinder(d.light_hole_d/2, lid_height + 1, align=MIN)
    bx, by = FLOORPLAN["BZ1"]
    for dx in (-3, 0, 3):
        lid -= Pos(bx + dx, by, d.base_height) * Cylinder(d.vent_d/2, lid_height + 1, align=MIN)
    return base, lid, build_parts(d)


def check(parts, d: Dimensions = D):
    base, lid, electronics = parts
    validate_netlist(load_netlist())
    assert d.height > d.base_height
    assert d.screw_x + d.boss_radius < d.length/2-d.wall
    assert d.screw_y + d.boss_radius <= d.width/2-d.wall + 1e-6
    for part, z0, z1 in ((base, 0, d.base_height), (lid, d.base_height, d.height)):
        bb = part.bounding_box()
        assert abs(bb.size.Y-d.width) < 1e-5
        assert abs(bb.min.Z-z0) < 1e-5 and abs(bb.max.Z-z1) < 1e-5
        assert part.volume > 0
    assert abs(base.bounding_box().size.X - (d.length + 2*d.ear_length)) < 1e-5
    assert abs(lid.bounding_box().size.X - d.length) < 1e-5
    for x, y in screw_centers(d):
        probe = Pos(x, y, 0) * Cylinder(d.screw_diameter/2-0.1, d.height)
        assert base.intersect(probe) is None and lid.intersect(probe) is None
    # The USB-C and button openings really cross the wall in front of J1/SW1.
    top = board_top(d)
    for y, z in ((d.usb_y, top + 1.6), (d.button_y, top + 1.75)):
        probe = Pos(-d.length/2 - 1, y, z) * Box(2*d.wall + 2, 0.5, 0.5)
        assert base.intersect(probe) is None, f"Wall opening at y={y} is blocked"
    # Every part lies inside the cavity and keeps clear of walls, bosses and
    # every other part.  Parts on PCB1 touch the board by design only.
    inner_x, inner_y = d.length/2 - d.wall, d.width/2 - d.wall
    board = next(p for p in electronics if p.ref == "PCB1")
    for p in electronics:
        bb = p.solid.bounding_box()
        assert bb.min.X >= -inner_x and bb.max.X <= inner_x, f"{p.ref} outside cavity in X"
        assert bb.min.Y >= -inner_y and bb.max.Y <= inner_y, f"{p.ref} outside cavity in Y"
        if p.in_cavity:
            assert bb.min.Z >= d.floor and bb.max.Z <= d.height - d.roof, f"{p.ref} outside cavity in Z"
        if p.on_board:
            assert abs(bb.min.Z - top) < 1e-6, f"{p.ref} not seated on PCB1"
            assert abs(bb.min.X) <= d.pcb_length/2 + 1 and abs(bb.max.X) <= d.pcb_length/2 + 1, f"{p.ref} off board"
            assert abs(bb.min.Y) <= d.pcb_width/2 and abs(bb.max.Y) <= d.pcb_width/2, f"{p.ref} off board"
            kx0, kx1, ky0, ky1 = ANT1_KEEPOUT
            if p.ref != "ANT1":
                assert bb.max.X <= kx0 or bb.min.X >= kx1 or bb.max.Y <= ky0 or bb.min.Y >= ky1, \
                    f"{p.ref} inside the LTE antenna keep-out"
        for shell, label in ((base, "base"), (lid, "capot")):
            gap = p.solid.distance_to(shell)
            assert gap >= d.min_clearance - 1e-6, f"{p.ref} touches {label} ({gap:.2f} mm)"
    for i, a in enumerate(electronics):
        for b in electronics[i+1:]:
            if {a.ref, b.ref} & {"PCB1"} and (a.on_board or b.on_board):
                continue
            gap = a.solid.distance_to(b.solid)
            assert gap >= d.min_clearance - 1e-6, f"{a.ref} touches {b.ref} ({gap:.2f} mm)"
    refs = {c["ref"] for c in load_netlist()["components"]}
    assert refs == {p.ref for p in electronics}, "Netlist and CAD part list differ"
    assert board.solid.distance_to(base) >= d.min_clearance


# ---------------------------------------------------------------- projection

def polyline(edge, n=18):
    # Topological edges are projected by OpenCascade; sample curved edges for SVG.
    if edge.geom_type.name == "LINE":
        pts = [edge.start_point(), edge.end_point()]
    else:
        pts = [edge.position_at(i/n) for i in range(n+1)]
    return [(p.X, p.Y) for p in pts]


class View:
    """One orthographic projection; maps both edges and 3D points to the sheet."""

    def __init__(self, shape: Shape, camera, up, cx, cy, scale=1, look_at=(0, 0, 18)):
        self.camera, self.up, self.look_at = camera, up, look_at
        self.cx, self.cy, self.scale = cx, cy, scale
        self.vis, self.hid = shape.project_to_viewport(camera, up, look_at=look_at)
        pts = [p for e in self.vis for p in polyline(e)]
        self.midx = (min(p[0] for p in pts)+max(p[0] for p in pts))/2
        self.midy = (min(p[1] for p in pts)+max(p[1] for p in pts))/2

    def xy(self, x, y):
        return self.cx+(x-self.midx)*self.scale, self.cy-(y-self.midy)*self.scale

    def point(self, v):
        marker = Pos(v.X, v.Y, v.Z) * Box(.02, .02, .02)
        vis, hid = marker.project_to_viewport(self.camera, self.up, look_at=self.look_at)
        p = (vis + hid)[0].start_point()
        return self.xy(p.X, p.Y)

    def svg(self, hidden=True):
        def path_for(edges, cls):
            out = []
            for e in edges:
                coords = " ".join("%.3f,%.3f" % self.xy(x, y) for x, y in polyline(e))
                out.append(f'<polyline class="{cls}" points="{coords}"/>')
            return "".join(out)
        return (path_for(self.hid, "hidden") if hidden else "") + path_for(self.vis, "object")


def section_svg(sections, cx, cy, d: Dimensions, cls="hatch", scale=1.0):
    """Draw the real planar section faces with hatch fill and their boundary edges."""
    markup=[]
    def xy(point):
        return (cx + point.X*scale, cy + (d.height/2 - point.Z)*scale)
    def close(a,b):
        return abs(a.X-b.X)+abs(a.Z-b.Z)<1e-5
    for sk in sections:
        for face in sk.faces():
            edges=list(face.outer_wire().edges())
            if not edges:
                continue
            chain=[edges.pop(0)]
            while edges:
                tip=chain[-1].end_point()
                match=next(((i,e,False) for i,e in enumerate(edges) if close(e.start_point(),tip)),None)
                if match is None:
                    match=next(((i,e,True) for i,e in enumerate(edges) if close(e.end_point(),tip)),None)
                if match is None:
                    raise ValueError('Section perimeter not closed')
                i,e,reverse=match
                chain.append(e.reversed() if reverse else e)
                edges.pop(i)
            points=[]
            for edge in chain:
                samples=[edge.start_point(),edge.end_point()] if edge.geom_type.name=='LINE' else [edge.position_at(i/24) for i in range(25)]
                points.extend(samples[:-1])
            path=' '.join(f'{x:.3f},{y:.3f}' for x,y in map(xy,points))
            markup.append(f'<polygon points="{path}" style="fill:url(#{cls})" class="object"/>')
    return ''.join(markup)


# ------------------------------------------------------------------- sheets

def assembly(parts):
    base, lid, electronics = parts
    return Compound(children=[base, lid] + [p.solid for p in electronics])


def P(x, y, z):
    return Pos(x, y, z).position


def sheet_one(parts, d: Dimensions):
    base, lid, electronics = parts
    full = assembly(parts)
    top_z = board_top(d)
    s = sheet_start(1, "ASSEMBLAGE GÉNÉRAL", "TA-TR-GA-01", "1,4:1 sauf indication")
    k = 1.4
    top = View(full, (0, 0, 200), (0, 1, 0), 106, 92, k)
    s.append(top.svg())
    s.append(txt(106, 146, "PLAN / DESSUS (CAPOT EN TRANSPARENCE) / 1,4:1", 3, "label", "middle"))
    x0, x1 = top.point(P(-d.length/2, 0, d.height))[0], top.point(P(d.length/2, 0, d.height))[0]
    y0, y1 = top.point(P(0, d.width/2, d.height))[1], top.point(P(0, -d.width/2, d.height))[1]
    ex0, ex1 = top.point(P(-d.length/2-d.ear_length, 0, 0))[0], top.point(P(d.length/2+d.ear_length, 0, 0))[0]
    s.append(dim_h(x0, x1, y0-8, y0-1, f"{d.length:g}"))
    s.append(dim_h(ex0, ex1, y0-15, y0-1, f"{d.length+2*d.ear_length:g} HORS TOUT"))
    s.append(dim_v(y0, y1, ex0-6, x0-1, f"{d.width:g}"))
    sy0, sy1 = top.point(P(0, d.screw_y, d.height))[1], top.point(P(0, -d.screw_y, d.height))[1]
    sx1 = top.point(P(d.screw_x, 0, d.height))[0]
    s.append(dim_v(sy0, sy1, ex1+8, sx1, f"{2*d.screw_y:g} C-C"))
    cy = top.point(P(0, d.usb_y, 0))[1]
    s.append(line(ex0-4, cy, ex1+4, cy, "cut"))
    s.append(txt(ex0-6, cy-1.5, "A", 3, "label-bold")); s.append(txt(ex1+4, cy-1.5, "A", 3, "label-bold"))

    front = View(full, (0, -200, 10), (0, 0, 1), 106, 176, k)
    s.append(front.svg())
    s.append(txt(106, 196, "ÉLÉVATION AVANT", 3, "label", "middle"))
    fy0, fy1 = front.point(P(0, 0, d.height))[1], front.point(P(0, 0, 0))[1]
    fx0 = front.point(P(-d.length/2-d.ear_length, 0, 0))[0]
    s.append(dim_v(fy0, fy1, fx0-6, fx0, f"{d.height:g}"))

    side = View(full, (-200, 0, 10), (0, 0, 1), 236, 176, k)
    s.append(side.svg())
    s.append(txt(236, 196, "PROFIL GAUCHE — USB-C ET BOUTON", 3, "label", "middle"))
    pu = side.point(P(-d.length/2, d.usb_y, top_z + 1.6))
    pb = side.point(P(-d.length/2, d.button_y, top_z + 1.75))
    s.append(balloon(pu[0], pu[1], pu[0]-14, pu[1]-22, "U"))
    s.append(balloon(pb[0], pb[1], pb[0]+16, pb[1]-22, "B"))
    s.append(txt(196, 216, f"U  port USB-C {d.usb_width:g} × {d.usb_height:g} (charge) — bouchon silicone", 2.4, "label"))
    s.append(txt(196, 221, f"B  perçage Ø{d.button_d:g} pour SW1 — membrane à prévoir", 2.4, "label"))

    # Exact section through U1, the GNSS patch and the USB-C port (Y = usb_y).
    cut = Plane(origin=(0, d.usb_y, 0), x_dir=(1, 0, 0), z_dir=(0, 1, 0))
    shells = [section(base, section_by=cut), section(lid, section_by=cut)]
    inner = [section(solid, section_by=cut) for p in electronics for solid in p.solid.solids()
             if solid.bounding_box().min.Y < d.usb_y < solid.bounding_box().max.Y]
    sc, scx, scy = 1.5, 322, 64
    s.append(section_svg(shells, scx, scy, d, scale=sc))
    s.append(section_svg(inner, scx, scy, d, "hatch2", scale=sc))
    s.append(txt(scx, 94, f"COUPE A–A / Y = +{d.usb_y:g} / 1,5:1", 3, "label", "middle"))
    s.append(txt(scx, 99, "Boîtier hachuré blanc • électronique hachurée jaune (PCB1, U1, U6, ANT2, J1, BT1)",
                 2.2, "sub", "middle"))
    top_y, bot_y = scy - d.height/2*sc, scy + d.height/2*sc
    left = scx - (d.length/2 + d.ear_length)*sc
    s.append(dim_v(top_y, bot_y, left-5, left, f"{d.height:g}"))
    pcb_y = scy + (d.height/2 - top_z)*sc
    right = scx + (d.length/2 + d.ear_length)*sc
    s.append(dim_v(pcb_y, bot_y, right+6, scx + d.length/2*sc, f"PCB {top_z:g}"))

    iso = View(full, (125, -140, 120), (0, 0, 1), 330, 170, 1.0, look_at=(0, 0, 10))
    s.append(iso.svg(hidden=False))
    s.append(txt(330, 214, "VUE ISOMÉTRIQUE ASSEMBLÉE / 1:1", 3, "label", "middle"))
    for (x, y, z), label, dx, dy in (((-22, 2, d.height), "LP1 voyant", -26, -10),
                                     ((-22, 14, d.height), "évents buzzer", -30, 2)):
        px, py = iso.point(P(x, y, z))
        s.append(line(px, py, px+dx, py+dy, "leader") + f'<circle cx="{px:.2f}" cy="{py:.2f}" r=".6" class="dot"/>')
        s.append(txt(px+dx-1, py+dy+1, label, 2.4, "label", "end"))
    s.append('</svg>')
    return ''.join(s)


def ring_positions(points, box, pad):
    """Spread balloons evenly around a rectangle, ordered by angle around its centre."""
    (x0, y0, x1, y1) = box
    cx, cy = (x0+x1)/2, (y0+y1)/2
    order = sorted(points, key=lambda kv: math.atan2(kv[1][1]-cy, kv[1][0]-cx))
    w, h = x1-x0+2*pad, y1-y0+2*pad
    perim = 2*(w+h)
    out = {}
    # Start the walk at the angle of the first item so leaders stay short.
    for i, (key, (px, py)) in enumerate(order):
        ang = math.atan2(py-cy, px-cx)
        t = (i + 0.5) / len(order)
        a = -math.pi + 2*math.pi*t
        a = (a + ang) / 2 if abs(a - ang) < math.pi/2 else a
        dx, dy = math.cos(a), math.sin(a)
        sx = (w/2) / abs(dx) if abs(dx) > 1e-9 else 1e9
        sy = (h/2) / abs(dy) if abs(dy) > 1e-9 else 1e9
        r = min(sx, sy)
        out[key] = (cx + dx*r, cy + dy*r)
    return out


def sheet_two(parts, d: Dimensions):
    base, lid, electronics = parts
    s = sheet_start(2, "CARTE TA-MB-01 ET IMPLANTATION", "TA-TR-GA-02", "2:1 (carte), 1:1")
    top_z = board_top(d)
    on_board = [p for p in electronics if p.on_board]
    pcb = next(p for p in electronics if p.ref == "PCB1")
    k = 2.0
    v = View(Compound(children=[pcb.solid] + [p.solid for p in on_board]), (0, 0, 200), (0, 1, 0), 108, 106, k)
    # LTE antenna keep-out, hatched on the board.
    kx0, kx1, ky0, ky1 = ANT1_KEEPOUT
    (ax, ay), (bx, by) = v.point(P(kx0, ky1, top_z)), v.point(P(kx1, ky0, top_z))
    s.append(f'<rect x="{ax:.2f}" y="{ay:.2f}" width="{bx-ax:.2f}" height="{by-ay:.2f}" style="fill:url(#hatch2)" class="frame"/>')
    s.append(v.svg(hidden=False))
    s.append(txt((ax+bx)/2, ay-1.5, "ZONE DÉGAGÉE ANTENNE LTE", 2.1, "accent", "middle"))
    px0, py0 = v.point(P(-d.pcb_length/2, d.pcb_width/2, top_z))
    px1, py1 = v.point(P(d.pcb_length/2, -d.pcb_width/2, top_z))
    pts = {p.ref: v.point(P(p.ports["C"].X, p.ports["C"].Y, top_z)) for p in on_board}
    spots = ring_positions(list(pts.items()), (px0, py0, px1, py1), 13)
    for p in on_board:
        (x, y), (tx, ty) = pts[p.ref], spots[p.ref]
        s.append(balloon(x, y, tx, ty, p.find))
        s.append(txt(tx + (5 if tx > (px0+px1)/2 else -5), ty + 1, p.ref, 2.2, "sub",
                     "start" if tx > (px0+px1)/2 else "end"))
    s.append(dim_h(px0, px1, py0-26, py0-15, f"{d.pcb_length:g}"))
    s.append(dim_v(py0, py1, px1+30, px1+16, f"{d.pcb_width:g}"))
    s.append(txt(108, py1+30, "01 CARTE TA-MB-01 — FACE COMPOSANTS / 2:1", 3, "label", "middle"))
    s.append(txt(108, py1+35, f"Épaisseur {d.pcb_thickness:g} • 4 encoches R{d.boss_radius+d.pcb_notch_gap:g} aux bossages "
                 f"• face supérieure à Z = {top_z:g}", 2.3, "sub", "middle"))

    under = View(lid, (0, 0, -200), (0, 1, 0), 318, 66, 1.0)
    s.append(under.svg(hidden=False))
    s.append(txt(318, 102, "CAPOT / FACE INTÉRIEURE / 1:1", 3, "label", "middle"))
    s.append(txt(318, 107, f"Ø{d.light_hole_d:g} guide de lumière LP1 • 3 évents Ø{d.vent_d:g} buzzer • zone GNSS sans métal",
                 2.2, "sub", "middle"))

    bt = next(p for p in electronics if p.ref == "BT1")
    lower = View(Compound(children=[base, bt.solid]), (0, 0, 200), (0, 1, 0), 318, 145, 1.0)
    s.append(lower.svg(hidden=False))
    c = lower.point(P(d.battery_x, 0, 7.5))
    s.append(balloon(c[0], c[1], c[0]+26, c[1]+24, bt.find))
    s.append(txt(318, 182, "BASE + BT1 SUR MOUSSE (CARTE RETIRÉE) / 1:1", 3, "label", "middle"))

    rules = ["RÈGLES D'IMPLANTATION",
             "• ANT1 en bord de carte, zone dégagée sans cuivre ni composant (contrôlée).",
             "• ANT2 face au capot polymère ; aucun métal au-dessus.",
             "• U2/U3 près du centre de la carte, fixée par 4 points rigides.",
             "• Batterie sous la carte : vérifier l'accord des antennes.",
             "• J1 et SW1 alignés sur les ouvertures de la paroi -X (contrôlé)."]
    for i, r in enumerate(rules):
        s.append(txt(236, 196 + i*5.6, r, 2.8 if i == 0 else 2.35, "label-bold" if i == 0 else "label"))
    s.append(line(222, 24, 222, 244, "thin"))
    s.append('</svg>')
    return ''.join(s)


EXPLODE = {"base": (0, 0, 0), "BT1": (0, 0, 16), "pcb": (0, 0, 34), "LP1": (0, 0, 52), "LID": (0, 0, 62)}


def exploded(parts, d: Dimensions):
    """Groups lifted along Z: base, battery, populated board, light pipe, lid."""
    base, lid, electronics = parts
    solids, moved = [base, Pos(*EXPLODE["LID"]) * lid], {}
    for p in electronics:
        off = EXPLODE.get(p.ref, EXPLODE.get(p.mount, (0, 0, 0)))
        solids.append(Pos(*off) * p.solid)
        moved[p.ref] = off
    return Compound(children=solids), moved


def view_bbox(view):
    xs, ys = [], []
    for e in view.vis:
        for x, y in polyline(e):
            sx, sy = view.xy(x, y)
            xs.append(sx); ys.append(sy)
    return min(xs), min(ys), max(xs), max(ys)
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

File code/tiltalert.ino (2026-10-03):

#include "TiltAlertCore.h"

// Validated Uno wiring: KY-020 OUT -> D2, KY-012 -> D3,
// red LED -> D13, KY-004 button -> D12 (active LOW).
const uint8_t tiltPin = 2;
const uint8_t buzzerPin = 3;
const uint8_t ledPin = 13;
const uint8_t buttonPin = 12;

tiltalert::Controller controller;

void printEvent(const char* event, uint32_t now) {
  // JSON Lines over USB serial. uptime_ms is time since boot, not a UTC date.
  Serial.print(F("{\"event\":\""));
  Serial.print(event);
  Serial.print(F("\",\"uptime_ms\":"));
  Serial.print(now);
  Serial.print(F(",\"count\":"));
  Serial.print(controller.count());
  Serial.print(F(",\"threshold\":"));
  Serial.print(tiltalert::kThreshold);
  Serial.println(F("}"));
}

void setup() {
  pinMode(tiltPin, INPUT);  // Existing circuit uses an external pull-down.
  pinMode(buttonPin, INPUT_PULLUP);
  pinMode(buzzerPin, OUTPUT);
  pinMode(ledPin, OUTPUT);
  digitalWrite(buzzerPin, LOW);
  digitalWrite(ledPin, LOW);

  Serial.begin(9600);
  const uint32_t now = millis();
  controller.begin(now, digitalRead(tiltPin) == HIGH,
                   digitalRead(buttonPin) == LOW);
  printEvent("ready", now);
}

void loop() {
  const uint32_t now = millis();
  const tiltalert::Events events = controller.update(
      now, digitalRead(tiltPin) == HIGH, digitalRead(buttonPin) == LOW);

  if (events.tiltRecorded) printEvent("tilt", now);
  if (events.alarmStarted) printEvent("alarm", now);
  if (events.reset) printEvent("reset", now);

  const uint8_t output = controller.alarmActive() ? HIGH : LOW;
  digitalWrite(buzzerPin, output);
  digitalWrite(ledPin, output);
}

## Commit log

2025-01-06 Final Version
    [wiring_diagram.brd]
2026-10-03 Firmware: testable core, debounced inputs, JSON Lines output, AVR + Wokwi simulation
    - TiltAlertCore.h: pure C++ state machine (debounce, 5-tilt alarm, latched reset, millis() wrap)
    - host tests (tests/) and avr8js simulation of the compiled binary
    - Wokwi circuit and captures of alarm, reset and serial log
    - Tinkercad guide (variant, not built)
    [tiltalert.ino]
2026-10-03 Hardware: Uno prototype sheets and V2 nRF9151 board with scripted checks
    - hardware/validated-uno: corrected netlist, schematic and breadboard layout, validated against the netlist
    - hardware/trace-v2: nRF9151 board (netlist.json, sourced components, open points)
    - cad: parametric enclosure + populated board, clearance/rail/bus/keep-out checks
    - four A3 sheets (assembly, board, single-page exploded view with 22 callouts, electrical architecture)
    [tiltalert-trace-assembly.step, tiltalert-trace-base.step, tiltalert-trace-base.stl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]
2026-10-03 README: product pitch with problem, solution, demos, blueprints and honest status
